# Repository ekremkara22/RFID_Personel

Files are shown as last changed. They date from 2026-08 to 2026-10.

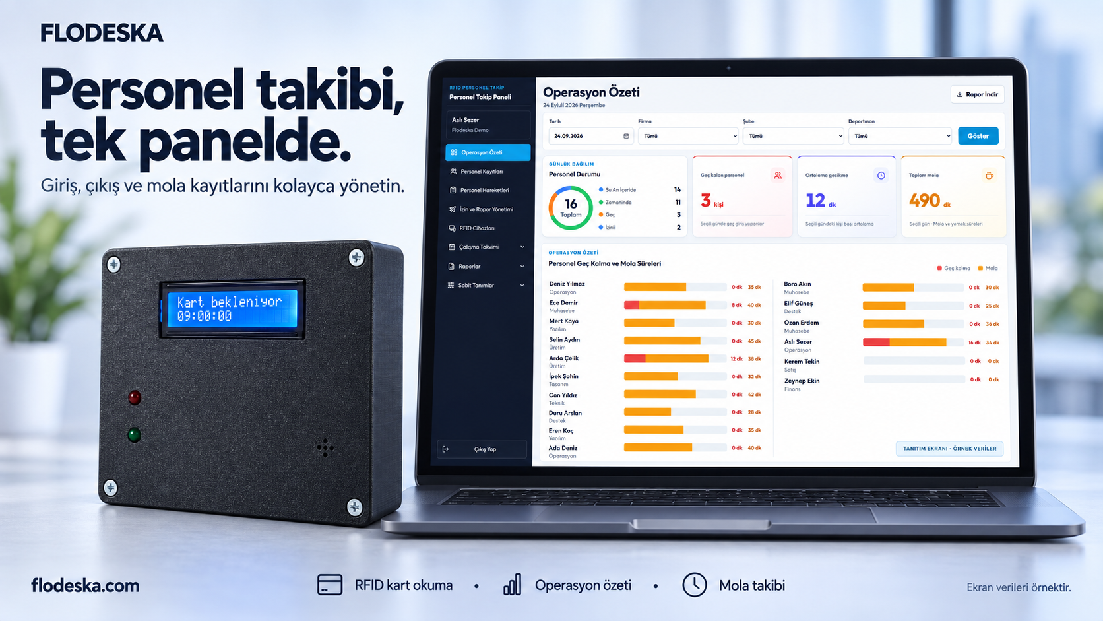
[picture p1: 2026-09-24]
public/images/marketing/flodeska-tanitim-yatay-v1.png

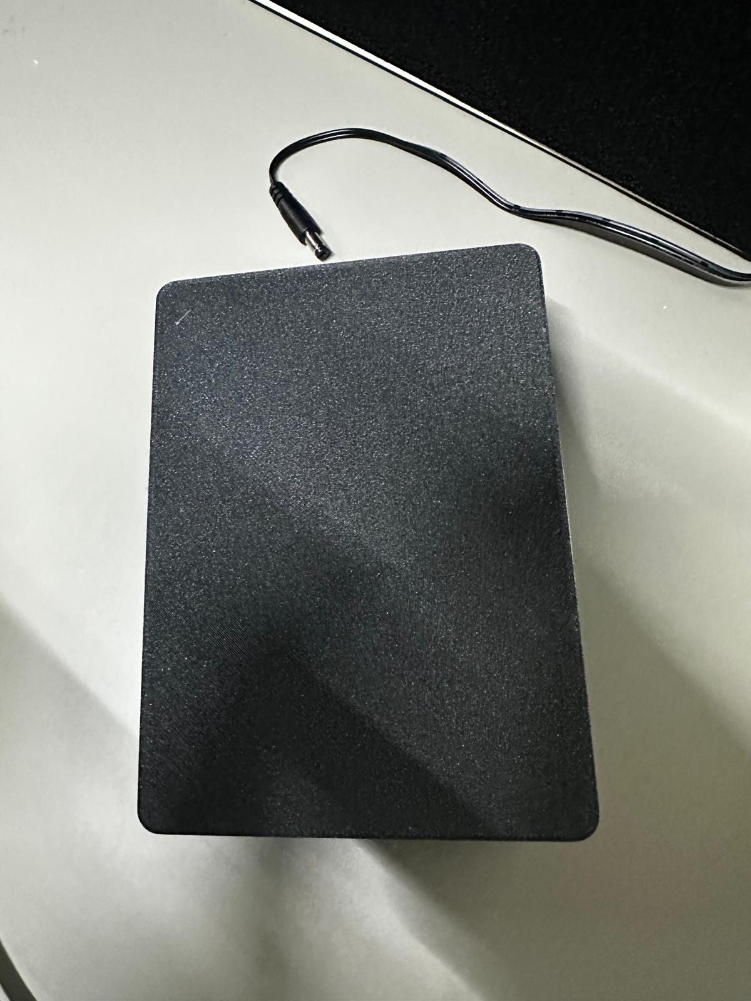
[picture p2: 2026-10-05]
UrunGorsel/Gorseller/WhatsApp Image 2026-09-24 at 16.05.19 (3).jpeg

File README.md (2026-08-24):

# RFID Personel Takip

RFID kart tabanli personel takip paneli. Bu repo web paneli, veritabani modeli ve ESP32/RFID cihaz entegrasyonu icin kullanilir; eski mobil uygulama kodlari devre disi birakilmistir.

## Getting Started

First, run the development server:

```bash
npm run dev
# or
yarn dev
# or
pnpm dev
# or
bun dev
```

Open [http://localhost:3000](http://localhost:3000) with your browser to see the result locally.

You can start editing the page by modifying `app/page.tsx`. The page auto-updates as you edit the file.

This project uses [`next/font`](https://nextjs.org/docs/app/building-your-application/optimizing/fonts) to automatically optimize and load [Geist](https://vercel.com/font), a new font family for Vercel.

## Learn More

To learn more about Next.js, take a look at the following resources:

- [Next.js Documentation](https://nextjs.org/docs) - learn about Next.js features and API.
- [Learn Next.js](https://nextjs.org/learn) - an interactive Next.js tutorial.

You can check out [the Next.js GitHub repository](https://github.com/vercel/next.js) - your feedback and contributions are welcome!

## Deploy on Vercel

The easiest way to deploy your Next.js app is to use the [Vercel Platform](https://vercel.com/new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) from the creators of Next.js.

Check out our [Next.js deployment documentation](https://nextjs.org/docs/app/building-your-application/deploying) for more details.

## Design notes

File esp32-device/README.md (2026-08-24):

# RFID Personel ESP32 Device

Bu klasor, firma girisine koyulacak ESP32 + OLED cihazinin firmware taslagini icerir.

## Yeni Wi-Fi kurulum akisi

Cihaz artik Wi-Fi adini ve sifresini koda sabitlemek zorunda degil.

1. ESP32 acildiginda kalici bellekte kayitli Wi-Fi bilgisi arar.
2. Kayitli bilgi varsa bu aga baglanmayi dener.
3. Baglanabilirse `https://flodeka.com/api/device/qr/sync` endpoint'inden QR token almaya devam eder.
4. Kayitli bilgi yoksa veya aga baglanamazsa kendi kurulum agini acar.
5. OLED ekranda kurulum agi gorunur: `RFIDPersonel-XXXXXX`.
6. Telefon ile bu Wi-Fi agina baglan.
7. Tarayici otomatik acilmazsa `http://192.168.4.1` adresine git.
8. ESP32'nin gordugu Wi-Fi aglarindan kendi agini sec, sifreyi gir ve kaydet.
9. OLED'de kaydedildi mesaji gorundukten sonra ESP32 uzerindeki reset tusuna bas.
10. Cihaz yeniden acilinca kaydedilen Wi-Fi bilgisi ile internete baglanir ve QR uretmeye devam eder.

## Mimari

ESP32 dogrudan MySQL veritabanina baglanmaz.

Daha dogru akis:

1. ESP32 Wi-Fi'ye baglanir.
2. Sunucudaki `/api/device/qr/sync` endpoint'ine `secretKey` ile POST atar.
3. Sunucu cihaz icin aktif `qrToken` degerini dondurur.
4. ESP32 bu token'i OLED uzerinde QR olarak gosterir.
5. ESP32 duzenli araliklarla endpoint'i tekrar cagirir.
6. Eger sunucudaki token degismisse OLED'deki QR da hemen degisir.

Bu sayede:

- 5 saniyelik token yenileme veritabaninda merkezi olarak yonetilir
- Personel basarili `Giris` veya `Cikis` yaptiginda backend token'i aninda yeniler
- ESP32 bir sonraki poll'da bunu gorup QR'i hemen yeniler

## Dosyalar

- `checkinqr_device/checkinqr_device.ino`: Arduino IDE / ESP32 icin ana firmware
- `qrcode.c`, `qrcode.h`: QR olusturma kutuphanesi

## Gerekli kutuphaneler

Arduino IDE Library Manager ile su kutuphaneleri kur:

- `Adafruit GFX Library`
- `Adafruit SSD1306`
- `ArduinoJson`
- `QRCode`

ESP32 core ile gelen su kutuphaneler de kullanilir:

- `WiFi`
- `WebServer`
- `DNSServer`
- `Preferences`
- `HTTPClient`
- `WiFiClientSecure`

## Donanim varsayimi

- Kart: ESP32 Dev Module
- Ekran: SSD1306 128x64 I2C OLED
- I2C adresi: `0x3C`
- Reset: ESP32 kart uzerindeki `EN/RST` tusu
- Wi-Fi durum LED'i: `GPIO 5` / kart uzerinde `D5`

## LED ve reset butonu baglantisi

Wi-Fi baglaninca yanacak yesil LED:

```text
ESP32 D5 / GPIO 5 -> LED uzun bacak (+)
LED kisa bacak (-) -> 220R veya 330R direnc -> GND
```

Harici reset butonu kullanmak istersen:

```text
Buton ucu 1 -> EN
Buton ucu 2 -> GND
```

Not: Harici reset butonu koda bagli degildir; ESP32'yi donanimsal olarak yeniden baslatir.

## Ayarlanacak alanlar

`checkinqr_device.ino` icindeki su degerleri kontrol et:

- `API_BASE_URL`: varsayilan `https://flodeka.com`
- `DEVICE_SECRET_KEY`: panelde tanimli cihaz secret key degeri

Wi-Fi bilgisi artik web kurulum ekranindan kaydedilir.

Istersen firmware icine ilk kurulum icin varsayilan Wi-Fi bilgisi gomulebilir:

```cpp
const char* DEFAULT_WIFI_SSID = "WiFi_Adi";
const char* DEFAULT_WIFI_PASSWORD = "WiFi_Sifresi";
```

Bu degerler bos birakilirsa cihaz ilk acilista kurulum agi acar.

## Sunucu endpoint'i

POST `https://flodeka.com/api/device/qr/sync`

Ornek body:

```json
{
  "secretKey": "cihaz-secret-key"
}
```

Ornek cevap:

```json
{
  "deviceId": "uuid",
  "deviceName": "On Kapi ESP32",
  "companyId": "uuid",
  "qrToken": "aktif-uuid-token",
  "qrUpdatedAt": "2026-04-11T12:00:00.000Z",
  "qrExpiresAt": "2026-04-11T12:00:05.000Z",
  "refreshIntervalSeconds": 5
}
```

## Onemli not

Backend tarafinda token 5 saniyede bir degisecek sekilde ayarli.
Ancak personel basarili `Giris` veya `Cikis` yaptiginda token hemen yenileniyor.

Bu nedenle ESP32 kodunda poll araligini 1 saniye tuttuk.
Boylece cihaz, 5 saniyeyi beklemeden yeni token'i hizlica alir.

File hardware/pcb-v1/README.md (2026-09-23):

# RFID taşıyıcı PCB V0.1 - V4 kutu

**Durum: elektrik bağlantıları tanımlanmış, parçaları yerleştirilmiş, bakır yolları henüz çizilmemiş ilk taslak. Üretime hazır değildir.**

Bu paket 30 pinli ESP32 DevKit V1'i sökülebilir iki soket üzerinde kullanır. Mevcut çalışan firmware'in GPIO bağlantıları korunur. ESP32, LCD veya RC522'nin fiziksel örnekleri bu çalışma sırasında ölçülmedi; kart çalıştırılmadı. Gerber üretilmedi.

## Dosyalar

- `rfid_carrier_v01.kicad_pro`: KiCad proje dosyası.
- `rfid_carrier_v01.kicad_sch`: gömülü sembolleri olan elektrik şeması; aynı isimli net etiketleri birbirine bağlıdır.
- `rfid_carrier_v01.kicad_pcb`: 128 × 58 mm, 1,6 mm, iki katmanlı taslak; net atamaları ve anten/vida bölgeleri var, yollar yok.
- `RFID_Carrier.pretty/`, `RFID_Carrier.kicad_sym`, kütüphane tabloları: taşınabilir yerel parçalar. Footprint'ler fiziksel doğrulama bekliyor.
- `connections.csv`: her bileşenin her bacağı ve bağlandığı hat.
- `bom.csv`: parça listesi; ESP32 modülü, LCD, RC522, iki LED, buzzer, kutu, kablo, eş soketler ve bağlantı elemanları ayrıca gerekir.
- `design.json`: parametrik elektrik ve yerleşim kaynağı.
- `pcb_yerlesim.png`: yerleşim görünümü; üretim çizimi değildir.
- `v4_geometry.json`: kaynak STL özetleri, dosya hash'leri ve kesitlerden bulunan geometriler.
- `validation.json`, `file_validation.json`: yapılan sınırlı kontroller ve yapılmayanlar.
- `../../output/pdf/rfid_pcb_v01_inceleme.pdf`: 1:1 mekanik kontrol sayfası ve devre özeti.

KiCad 8+ dosya sözdizimi hedeflendi. Bu makinede KiCad bulunmadığından uygulamada açılış, ERC ve DRC henüz doğrulanmadı. `.kicad_pro` dosyasını açın; şema ve kartta karşılıklı referans UUID'leri bulunur. Şemadan PCB güncellemesi yapmadan önce yedek alın.

## V4'ten ölçülen mekanik düzen

Kaynaklar `output/enclosure_v4/gövde.stl` ve `kapak.stl` dosyalarıdır. STL birimi proje bağlamına göre mm kabul edilir. Dosyalardaki negatif yerleşim koordinatları normalize edildi; **gövdenin minimum X/Y köşesi (0,0)** kabul edilir. Çizimler bu XY koordinatlarını gösterir, kullanıcı bakış açısına göre ön/arka isimlendirme yapılmaz.

| Özellik | Değer |
|---|---|
| Gövde dışı | 150 × 110 × 52 mm |
| Kapak STL sınırları | 150 × 110 × 8,498 mm; bu üçüncü ölçü ayaklarla toplam zarf, kapak et kalınlığı değildir |
| PCB sınırı | X=4…132; Y=39…97 mm |
| PCB boyutu | 128 × 58 × 1,6 mm |
| PCB alt yüzeyinin hedef yüksekliği | Gövde STL tabanından Z=10 mm |
| ESP32 bölgesi delikleri | X=8,05 / 51,95; Y=43,10 / 66,90; geçiş çapı 2,8 mm |
| Eski plaket bölgesi delikleri | X=83,41 / 126,59; Y=48,41 / 91,59; geçiş çapı 3,2 mm |
| Delik merkezlerinin STL kesitleriyle farkı | Taslak kontrolünde 0,06 mm'den az; baskı toleransı değildir |

Sekiz ayağın tepe düzlemi Z=10 mm. Kart bu ayakların üzerine oturur; eski ayrı delikli plaket çıkarılır. ESP32 PCB'ye takılır. Sol bölgedeki vidaların başları ESP32 altında kalabilir: önce taşıyıcı kart vidalanır, sonra ESP32 takılır. Uygun küçük başlı vidalar/yalıtkan pullar seçilir. Mevcut V4 STL dosyaları değiştirilmedi.

**USB yüksekliği kesinleşmedi:** mevcut gövde USB açıklığı yaklaşık Z=9…21 mm. Taşıyıcı PCB ve soket ESP32'yi yükseltir. DevKit'in alt yüzeyi yaklaşık `10 + 1,6 + soketin etkin yüksekliği` mm olur. Soket yüksekliği, USB metal gövdesi ve takılı kablo fişi birlikte denenmelidir. Gerekirse düşük profilli soket veya V4 yan pencere revizyonu gerekir. Kutuya kusursuz oturduğu iddia edilmez.

Kapak, gövdeyle montaj konumuna çevrilmeden LCD/RC522 koordinatları doğrudan üst üste konulamaz. Bu nedenle taslak kapak modüllerine doğrudan geçmeli soket kullanmaz; esnek kablo bağlantısı bırakır. DevKit dış zarfı ve soket yeri önceki proje ölçülerinden varsayımdır, V4 STL ESP32 pinlerini içermez.

## Elektrik düzeni

`J1 → F1 → +5V` hattı LCD, buzzer ve U1'i besler. `JP1` takılıyken ESP32 VIN'e gider. ESP32'nin mevcut regülatöründen alınan 3V3 RC522'yi besler. Bütün GND'ler ortaktır.

- **J6/J7:** iki 1×15 dişi soket. 2,54 mm pin adımı, **25,40 mm sıra arası varsayım**. Üstten PCB görünümünde USB solda, anten sağda. J6 soldan VIN ile; J7 soldan 3V3 ile başlar. `connections.csv` bütün sırayı verir. Kart üzerindeki gerçek etiketlerle tek tek karşılaştırılmalı.
- **J2:** RC522, pinler soldan `SS, SCK, MOSI, MISO, IRQ(NC), GND, RST, 3V3`. Reader soketinin sırası farklıysa kablo çaprazlanır; isimler esas alınır. R7/R8 SCK ve MOSI üzerinde 33 Ω seri dirençtir. SS, R6 ile 3V3'e çekilir.
- **J3:** LCD'nin 1…16 pinleriyle aynı numaralar; RW GND, D0…D3 boş. Altı sinyal U1 üzerinden gider. Bu tasarım I2C değildir.
- **U1:** SN74AHCT244N, DIP-20. 5V beslemede 3,3V girişleri kabul ederek LCD'ye 5V sinyal verir. Her iki OE GND; kullanılmayan girişler GND, çıkışlar NC. RN1 LCD kontrol girişlerini açılışta düşük tutar. RN1, ortak ucu pin 1 olan **bussed** 8×10 kΩ SIP-9 olmalıdır.
- **RV1:** 10 kΩ kontrast trimeri. Pin 1 GND, 2 sürgü/VO, 3 +5V; gerçek modelin pin sırası doğrulanmalı.
- **R5:** LCD arka aydınlatması için başlangıç 330 Ω. Loş olabilir; LCD veri sayfası ve ölçülen akıma göre seçilir. Mevcut LCD'de dahili direnç bulunması doğrulanmadan kısa devre edilmez.
- **J4:** yeşil anot, GND, kırmızı anot, GND. R1/R2 220 Ω seri dirençler kart üzerindedir.
- **J5:** pin 1 +5V, pin 2 Q1 kolektörü. GPIO14 → R3 1 kΩ → BC337 base; emitter GND. R4 100 kΩ base-emitter direnci açılışta kapalı tutar. D1 katot/çizgi +5V, anot kolektör. D1'in ve base sürüşünün uygunluğu gerçek buzzer akımına göre doğrulanmalı; BC337'nin katalog maksimum akımı bu devrenin izin verilen buzzer akımı değildir.
- **C1:** 470 µF/16V; mevcut parçanın çapı/pin aralığı 8/3,5 mm varsayımıyla uyuşmuyorsa footprint değiştirilir. Yerel 100 nF ve 10 µF kondansatörler eklendi.
- **TP1/TP2/TP3:** +5V, +3V3 ve GND ölçüm noktaları.

F1, MF-R075 0,75 A PTC ön seçimidir. Kutudaki sıcaklık, başlangıç akımı ve üzerindeki gerilim düşümü ölçülmeden sonlandırılmaz. 5V hattı U1 için en az 4,5V olmalı. Burada 9/12V düşürücü, ters kutup koruması veya USB/harici güç OR-ing devresi yoktur. Regüle 5V ve doğru polarite gerekir.

**USB ile harici besleme aynı anda bağlanmaz.** JP1 çift güç kaynağı güvenliği sağlamaz. İlk prototipte programlamayı ESP32'yi soketten çıkarıp USB'ye bağlayarak yapın; güç kesikken yeniden takın. Sonraki revizyonda servis sırasında eşzamanlı güç istenirse uygun güç seçimi eklenir.

## Kablo kalabalığı nasıl azalıyor?

ESP32 ile dirençler, transistör, besleme dağıtımı ve kondansatörler arasında kablo olmayacak; bunlar PCB yollarına dönüşecek. Kapaktaki modüller için dört demet kalacak: LCD (16'lı şerit, 12 aktif hat), RC522 (8'li, 7 aktif), LED'ler (4'lü), buzzer (2'li). Jak için ayrıca iki güç teli var. Henüz yollar çizilmediği için mevcut dosya bu işlevi fiziksel olarak gerçekleştiren bitmiş kart değildir.

J2…J5 için çizilen footprint'ler genel 2,54 mm pin sıralarıdır; belirli bir kilitli konektörün mekanik zarfı doğrulanmış değildir. Sipariş öncesi tek seri kutuplu/kilitli soket seçilip gerçek footprint'e geçilir. Kablo pin 1 yönleri iki uçtan multimetreyle kontrol edilir.

## Üretimden önce kapanması gerekenler

1. PDF'yi **gerçek boyut/%100**, sayfaya sığdırma kapalı basın; 50 mm ölçek çizgisini cetvelle ölçün. DevKit soketleri, sekiz vida ve kart sınırını gerçek parçalarla kontrol edin.
2. DevKit iki sıra merkezini, USB yönünü, J6/J7 pin sırasını, soket yüksekliğini ve kablo fişi açıklığını doğrulayın. 30 pinli DevKit V1 adı tek başına bütün klonların aynı ölçüde olduğunu garanti etmez.
3. Trimer, terminal, kondansatör, transistör ve soket modellerini kesinleştirin; footprint'leri düzeltin. Boşluk kontrolleri yalnızca taslaktaki zarflara dayanır.
4. KiCad'de açın. Şema ERC uyarılarını gerçek güç kaynaklarını ve bağlantıları göz önünde bulundurarak çözün. Bağlantı etiketlerinin şemadan çıkan netlist ile eşleştiğini doğrulayın; sadece bütün uyarıları susturmayın.
5. İki katmanlı bakır yolları çizin. Başlangıç kuralları: sinyal 0,30 mm; güç 0,80 mm; minimum açıklık 0,25 mm; bunlar üretici kuralları ve akım/ısı hesabıyla sonlandırılır. Wi-Fi anten bölgesinde iki katmanda da bakır, via ve hat bırakmayın. Şu anki anten boşluğu muhafazakâr bir taslak; gerçek anten sınırı ve üretici önerileriyle doğrulanmalı. Vida bölgelerinden bakır geçirmeyin. Uygun bölgelerde GND dolgusu ve kısa dönüş yolları oluşturun.
6. DRC, açık bağlantı kontrolü, gerçek bileşenlerle 3B çakışma ve kapak kapalı halde kablo boşluklarını kontrol edin. Eksiksiz 3B doğrulama yapılmadan "V4'e kesin uyumlu" kabul etmeyin.
7. Gerber ve delik dosyalarını **bu adımlardan sonra** üretin. Küçük deneme adedi yaptırın; nihai BOM'a göre elle monte edin.
8. Akım sınırlı regüle 5V ile modüller çıkarılmış halde kısa devre/besleme kontrolü yapın. Gücü kesip ESP32'yi ekleyin, 3V3 ölçün; sonra ekran, RFID ve buzzerı sırayla deneyin. Wi-Fi gönderimi + arka ışık + buzzer birlikteyken reset/gerilim düşümü olmamalı. Kapak açık/kapalı RFID okuma mesafesini ve Wi-Fi kararlılığını karşılaştırın.

## İkinci sürüm: geliştirme kartını kaldırmak

İlk PCB donanım arayüzünü sabitler: LCD paralel, RC522 SPI, iki LED, buzzer. İkinci revizyonda DevKit yerine uygun bir **ESP32 modülü** doğrudan lehimlenebilir. ESP32 çipini ve RF devresini sıfırdan tasarlamak zorunlu değildir.

Bu değişimde DevKit'in sağladığı 3,3V regülatör, EN/BOOT devresi, programlama arayüzü, besleme ayırma ve test noktaları ana karta taşınır. Aynı ESP32 ailesi/modülü ve GPIO'lar korunursa uygulama mantığı büyük ölçüde yeniden kullanılabilir; farklı aileye geçiş yeniden pin/çevrebirim doğrulaması gerektirir.

"Standart gömülü yazılım" için sonraki iş: pinleri kart profiline ayırmak, sürüm numaralı derleme ve bağımlılıklar, cihaz kimliği/provizyonlama, güvenli güncelleme ve test prosedürü oluşturmak. Geliştirme kartını kaldırmak tek başına yazılımı standartlaştırmaz. Bu çalışmada çalışan `.ino` değiştirilmedi.

## Kaynaklar

- Yerel bağlantılar: `esp32-device/rfid_personel_device/BAGLANTI_DOKUMANI.md` ve aynı dizindeki firmware.
- [TI SN74AHCT244 veri sayfası](https://www.ti.com/lit/ds/symlink/sn74ahct244.pdf): pin düzeni, TTL giriş eşiği, besleme aralığı.
- [onsemi BC337 veri sayfası](https://www.onsemi.com/pdf/datasheet/bc337-fsc-d.pdf): C-B-E bacak sırası ve elektriksel sınırlar.
- [Bourns MF-R veri sayfası](https://bourns.com/docs/product-datasheets/mf-r.pdf): PTC ölçüleri, akım ve sıcaklık karakteristikleri.
- [Espressif ESP32 yerleşim kılavuzu](https://docs.espressif.com/projects/esp-hardware-design-guidelines/en/latest/esp32/pcb-layout-design.html): modül anten bölgesi ve yerleşim.
- [KiCad PCB dosya biçimi](https://dev-docs.kicad.org/en/file-formats/sexpr-pcb/) ve [şema biçimi](https://dev-docs.kicad.org/en/file-formats/sexpr-schematic/).

## Yeniden üretme

Python 3, numpy, Pillow; PDF için reportlab. Çalışma dizini projenin kökü:

```text
python hardware/pcb-v1/inspect_stl.py
python hardware/pcb-v1/build_design.py
python hardware/pcb-v1/validate_files.py
python hardware/pcb-v1/build_pdf.py
```

Üreteç aynı adlı çıktıları yeniden yazar. KiCad'de el ile yapılan değişikliklerin üzerine çalıştırmayın; üreteci veya dosyaları tek kaynak olarak seçin. Hiçbir komut kaynak STL'leri veya firmware'i değiştirmez.

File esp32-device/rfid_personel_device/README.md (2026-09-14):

# RFID Personel ESP32 Cihaz Kodu

Bu klasor tek RFID okuyucu ile personel giris-cikis, mola giris-cikis ve mesai cikis hareketlerini web API'ye gondermek icin hazirlandi.

## Gerekli Arduino kutuphaneleri

- MFRC522
- LiquidCrystal
- ArduinoJson

## Varsayilan pinler

| Parca | ESP32 pini |
| --- | --- |
| RC522 SDA/SS | GPIO 5 |
| RC522 RST | GPIO 27 |
| RC522 SCK | GPIO 18 |
| RC522 MISO | GPIO 19 |
| RC522 MOSI | GPIO 23 |
| 2x16 paralel LCD RS | GPIO 32 |
| 2x16 paralel LCD E | GPIO 25 |
| 2x16 paralel LCD D4 | GPIO 22 |
| 2x16 paralel LCD D5 | GPIO 21 |
| 2x16 paralel LCD D6 | GPIO 16 / RX2 |
| 2x16 paralel LCD D7 | GPIO 17 / TX2 |
| Yesil LED | GPIO 26 |
| Kirmizi LED | GPIO 33 |
| Aktif buzzer sinyali | GPIO 14 / D14 |

LCD, I2C donusturucu olmadan 4-bit paralel modda kullanilir. Ayrintili guc,
kontrast ve buzzer baglantisi icin `BAGLANTI_DOKUMANI.md` dosyasina bak.

## Ilk kurulum

1. Arduino IDE icinde `rfid_personel_device.ino` dosyasini ac.
2. Kart olarak ESP32 sec.
3. Kodu ESP32'ye yukle.
4. Cihazda kayitli Wi-Fi/secret yoksa `RFIDPersonel-XXXXXX` adinda ag acar.
5. Telefonda bu aga baglan ve tarayicida `192.168.4.1` adresini ac.
6. Wi-Fi, API adresi ve cihaz secret key bilgisini kaydet.

Varsayilan API adresi:

```text
http://13.143.223.183:3002
```

Secret key bilgisini firma admin panelindeki RFID cihaz detayindan alabilirsin.

## Calisma mantigi

- Cihaz baglandiginda `/api/device/heartbeat` endpoint'ine bilgi yollar, panelde aktif gorunur.
- RFID kart okutulunca `/api/device/rfid/scan` endpoint'ine kart UID bilgisini gonderir.
- Web tarafinda hareket turu calisma takvimine gore tahmin edilir:
  - Gunun ilk hareketi: giris
  - Mola baslangic/bitiş saatlerine +-30 dakika yakin hareket: mola giris/cikis
  - Mesai bitisine +-30 dakika yakin hareket: cikis
  - Yanlis tahmin olursa firma admini Personel Hareketleri sayfasindan kaydi duzeltebilir.

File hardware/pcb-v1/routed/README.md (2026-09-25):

# RFID taşıyıcı PCB V0.2 — V4 kutu

Bu klasör V0.1 yerleşim taslağının bakır yolları çizilmiş prototip revizyonudur.
30 pin ESP32 DevKit V1 sökülebilir iki 1×15 dişi sokete takılır. Firmware GPIO
bağlantıları, V4 kart sınırı ve sekiz vida deliği korunur.

**Fiziksel prototip henüz üretilmedi veya çalıştırılmadı.** Dijital kontrollerin
sonuçları `validation.json`, `drc.json` ve `erc.json` içindedir. Siparişten önce
aşağıdaki üç fiziksel kontrol yapılmalıdır; bu dosyalar ölçülmemiş parçaların
mekanik uyumunu garanti etmez.

## Açılacak dosyalar

- `rfid_carrier_v01.kicad_pro`: proje; dosya adı şema/PCB referanslarını korumak için sabit kaldı, revizyon V0.2'dir.
- `rfid_carrier_v01.kicad_pcb`: iki katmanlı bakır yolları ve GND dolguları.
- `rfid_carrier_v01.kicad_sch`: elektrik şeması; global hat adları PCB ile aynıdır.
- `pcb_routed.png`: gerçek PCB geometrisinden üretilen üst/alt bakır görünümü.
- `mechanical_1to1.svg`: fiziksel parçalarla kontrol için %100 boyutta baskı şablonu.
- `gerber/`: iki bakır, iki maske, iki baskı katmanı, kart sınırı ve ayrı PTH/NPTH delik dosyaları.
- `connections.csv`, `bom.csv`: bağlantılar ve taşıyıcı kartın parça listesi.
- `native.net`: KiCad'in gerçek şemadan dışa aktardığı netlist.
- `validation.json`: şema–PCB–kaynak bağlantı karşılaştırması, hat uzunlukları ve PCB SHA-256 özeti.
- `RFID_Carrier.pretty/`, `RFID_Carrier.kicad_sym`, `*-lib-table`: proje ile taşınan yerel kütüphaneler.

Bir üst klasördeki V0.1 dosyaları ve eski inceleme PDF'si arşiv taslağıdır;
üretim için bu revizyonun dosyaları esas alınır.

## Tasarım kuralları ve değişiklikler

| Özellik | V0.2 |
|---|---|
| Kart | 128 × 58 mm, 1,6 mm, 2 katman; başlangıç 35 µm / 1 oz bakır |
| Kart koordinatları | V4 gövdesi normalize XY; X=4…132, Y=39…97 mm |
| Sinyal yolları | 0,30 mm |
| Güç yolları | 0,50 mm; GND ayrıca iki yüzeyde dolgu |
| Minimum elektriksel açıklık | 0,20 mm |
| Via | 1,00 mm bakır / 0,50 mm delik |
| ESP32 soket pedleri | 1,60 mm bakır / 1,00 mm delik; 2,54 mm adım |
| Soket sıra merkezleri | **25,40 mm varsayım — gerçek kartta ölçülecek** |
| Anten boşluğu | X=49…76, Y=39…85 mm; iki katmanda yol/via/dolgu yok |
| Vida boşlukları | 2,8 mm delikte 3,0 mm; 3,2 mm delikte 3,5 mm yarıçaplı bakırsız bölge |

V0.1'deki 0,80 mm güç yolu ve 0,25 mm açıklık önerisi bu yerleşimde soket
sıralarından geçişi engellediği için revize edildi. R7/R8 seri dirençleri ESP32
tarafına alındı; F1, C3, C5, Q1 ve RV1 montaj boşlukları düzeltildi. Güç
kaynakları şemada PWR_FLAG ile belirtildi. Kontroller için ihlal istisnası
eklenmedi. NPTH deliklerin koruma bölgesinde bulunabilmesi için bu bölgelerde
pad yasağı kullanılmaz; gerçek bileşen bakır pedleri ayrıca denetlenir.

## Siparişten önce üç kontrol

1. **ESP32:** iki pin sırası merkezini ölçün; 25,40 mm olmalı. Üstten bakışta
   USB solda, anten sağda; J6 soldan VIN, J7 soldan 3V3 ile başlar. Kart
   etiketlerini `connections.csv` ile tek tek eşleştirin.
2. **Kutu:** `mechanical_1to1.svg` dosyasını gerçek boyut / %100 basın; 50 mm
   çizgiyi cetvelle doğrulayın. Sekiz vida, kart sınırı, soket yüksekliği ve USB
   fişini V4 baskıda deneyin. PCB altı hedef Z=10 mm; mevcut USB penceresi
   yaklaşık Z=9…21 mm. Soket ESP32'yi yükselttiği için pencere değişikliği gerekebilir.
3. **BOM:** RV1 sürgü bacağı, J1 5,08 mm terminal, BC337 C-B-E, elektrolitik
   çap/adım, RN1 ortak bacak ve seçilen dişi soketlerin gövdelerini kontrol edin.
   J2…J5 genel 2,54 mm pin sıralarıdır; kilitli konnektör gövdeleri doğrulanmadı.

## Montaj ve ilk çalıştırma

- J1 yalnız **regüle 5 V DC** içindir. 12 V girişi, ters kutup koruması ve USB
  ile harici güç arasında otomatik seçim devresi yoktur. İlk programlamada
  ESP32'yi taşıyıcıdan çıkarıp USB ile programlayın. Harici beslemeyle kullanımda JP1 takılır.
- U1 **SN74AHCT244N DIP-20** olmalıdır. RN1 ortak ucu pin 1 olan 8×10 kΩ
  bussed SIP-9 ağıdır. LCD paralel 4-bit arayüz kullanır; I2C adaptör gerekmez.
- J2 RC522 sadece 3,3 V'tur. Soket sırası isimle eşleştirilir; kablo renkleri
  esas alınmaz. RFID kablosunu kısa tutun. Uzun bakır hatların/kablonun gerçek
  SPI okuma kararlılığı donanım üzerinde denenmelidir.
- R5=330 Ω LCD arka ışığı için başlangıç değeridir; ekranın gerçek akımı ve
  dahili direnci ölçülmeden köprülemeyin. Buzzer, Q1 ve D1 uygunluğu gerçek
  buzzer akımına bağlıdır. F1'in 0,75 A değeri kart için doğrulanmış akım kapasitesi değildir.
- Önce modüller çıkarılmışken kısa devre ve kutup kontrolü yapın. Akım sınırlı
  5 V ile besleyin; sonra gücü kesip ESP32, ekran, RC522 ve buzzerı sırayla ekleyin.
  Wi-Fi + arka ışık + buzzer eşzamanlı çalışırken 5 V / 3V3 düşümünü, resetleri,
  sıcaklığı ve kapak kapalı RFID menzilini kontrol edin.

## Doğrulama ve yeniden üretme

Doğrulama için resmi imzalı KiCad **10.99.0-4384-g95775e4647** CLI kullanıldı.
PCB/şema kaynakları KiCad 8 dosya sözdizimini korur; KiCad 8 uygulamasıyla
ayrıca denenmedi. Freerouting yerel çalıştırıldı; tasarım harici yönlendirme
servisine yüklenmedi. Donanım güç/ısı, sinyal bütünlüğü veya RF laboratuvar testi yapılmadı.

`prepare.py` yerleşim ve şema kaynağını üretir ve **mevcut bakır yollarını siler**.
`export_dsn.py` yönlendirme girdisini, `import_ses.py` SES'ten bakır yollarını
oluşturur. `finish_board.py` GND bölgelerini ekler; dolgu KiCad tarafından
yapılır. `review.py` gerçek PCB dosyasından kontrol raporu ve görsel üretir.
El ile düzenlenmiş PCB üzerine `prepare.py` çalıştırmayın.

Şema değişikliğinde ERC, şema–PCB netlist karşılaştırması ve DRC; her PCB
değişikliğinde dolgu yenileme, tüm DRC kontrolleri ve Gerber/delik dışa aktarımı
tekrarlanmalıdır. `validation.json` içindeki SHA-256, raporun hangi PCB'ye ait
olduğunu gösterir.

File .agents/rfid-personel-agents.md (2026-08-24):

# RFID Personel Takip Agent Yapisi

Bu dosya projede calisirken sorumluluk alanlarini ayirmak icin kullanilir.

## Ana Orchestrator

- Is akisini parcalara ayirir ve degisiklikleri tek hedefe baglar.
- Next.js dokumanlari yerelde varsa once `node_modules/next/dist/docs/` altindaki ilgili rehberi kontrol eder.
- Deploy, test ve geri bildirim akisini kapatir.
- Tum agent'lar web ekranlarini mobil ve tablet kullanimina uygun dusunur; ozellikle Firma Admin panelinde tablo, form ve dashboardlar dar ekranda okunabilir ve kullanilabilir kalmalidir.

## Personel Agent

- `src/app/dashboard/employees` ekranlari ve personel server action'larindan sorumludur.
- RFID kart alanlari, personel arama, duzenleme, silme ve aktivasyon akisini korur.
- Personel kayit, rapor ve hareket ekranlarini masaustu kadar tablet ve mobil kullanimda da islenebilir tutar.
- Koordinat, GPS veya mobil uygulama bagimliligi eklemez.

## Firma Agent

- Super admin firma listeleme, firma detay, firma admin bilgileri ve firma silme akisini yonetir.
- Firma Admin deneyiminde dashboard, rapor, izin ve sabit tanim ekranlarinin responsive davranisini korur.
- Firma detayinda cihaz atama islemlerinin sadece super admin yetkisinde kalmasini saglar.

## SQL Agent

- `prisma/schema.prisma`, seed verileri ve veritabani gecislerinden sorumludur.
- RFID kart ID alanini benzersiz tutar.
- Dinamik QR token, enlem, boylam ve konum dogrulama kolonlarini geri getirmez.

## Cihaz Agent

- `src/app/dashboard/devices` ve `src/app/api/device/rfid/scan` alanlarini yonetir.
- Firma adminin sadece kendisine atanmis cihazlari gormesini ve cihaz adini duzenlemesini saglar.
- ESP32 firmware fazina gecilene kadar web/API sozlesmesini sade ve kararlı tutar.

## ESP32 Agent

- Web tabani tamamlandiktan sonra `esp32-device` altindaki firmware'i RFID okuyucu akisana cevirir.
- Hedef API: `POST /api/device/rfid/scan`
- Cihazdan beklenen minimum veri: `secretKey`, `rfidCardId`.

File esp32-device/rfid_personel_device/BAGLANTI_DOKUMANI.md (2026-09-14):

# ESP32 RFID Personel Cihazı — Montaj ve Bağlantı Belgesi

Bu belge çalışan `rfid_personel_device.ino` firmware'indeki pinlere göre, kalıcı
lehimli montaj sırasında çıktı alınıp kullanılmak üzere hazırlanmıştır.

## 1. Önemli güvenlik kuralları

- Bütün bağlantıları adaptör prizden çekiliyken yap.
- Adaptör çıkışı regüle `5V DC / 1A` olmalıdır. 9V veya 12V bağlama.
- Adaptör `+5V` hattını yalnızca ESP32 `VIN`, LCD ve buzzer beslemesinde kullan.
- ESP32 `3V3` pinine kesinlikle 5V bağlama.
- RC522'ye kesinlikle 5V verme; yalnızca ESP32 `3V3` pininden besle.
- Elektrolitik kondansatörü ters bağlama.
- Adaptör VIN'e bağlıyken ESP32'ye bilgisayar USB'sinden ayrıca güç verme.
- İlk enerjiyi vermeden önce multimetreyle kısa devre ve gerilim kontrolü yap.

## 2. Kullanılacak parçalar

- ESP32 geliştirme kartı (`VIN`, `3V3` ve `GND` pinli)
- RC522 RFID okuyucu
- 2x16 paralel LCD (I2C dönüştürücüsüz)
- Yeşil LED
- Kırmızı LED
- 2 adet `220 ohm` LED direnci
- 5V aktif buzzer
- 1 adet `BC337` NPN transistör
- 1 adet `1K ohm` buzzer base direnci
- 1 adet `470 uF / 16V` elektrolitik kondansatör
- 1 adet `100 nF` seramik kondansatör
- Regüle `5V DC / 1A` adaptör
- Jak soketi, klemens, kablo ve pertinaks

`2N2222` bu montajda kullanılmayacak; BC337 için yedek olarak saklanacaktır.
Transistörlerin bacak sıraları aynı olmayabileceği için birbirlerinin yerine
kontrol etmeden takılmamalıdır.

Manyetik/bobinli buzzer kullanılıyorsa ayrıca `1N4148` veya `1N4007` koruma
diyodu gerekir. Bu belge iki bacaklı 5V aktif buzzerı esas alır.

## 3. ESP32 pin özeti

| Görev | ESP32 kart etiketi | GPIO |
| --- | --- | --- |
| RC522 SDA/SS | D5 | GPIO 5 |
| RC522 SCK | D18 | GPIO 18 |
| RC522 MOSI | D23 | GPIO 23 |
| RC522 MISO | D19 | GPIO 19 |
| RC522 RST | D27 | GPIO 27 |
| LCD RS | D32 | GPIO 32 |
| LCD E | D25 | GPIO 25 |
| LCD D4 | D22 | GPIO 22 |
| LCD D5 | D21 | GPIO 21 |
| LCD D6 | RX2 | GPIO 16 |
| LCD D7 | TX2 | GPIO 17 |
| Yeşil LED | D26 | GPIO 26 |
| Kırmızı LED | D33 | GPIO 33 |
| Buzzer kontrolü | D14 | GPIO 14 |

`VN`, VIN değildir. `VN/GPIO39` bu montajda kullanılmayacaktır.

## 4. Jak soketi ve ana güç girişi

Üç bacaklı jak soketinde genellikle `+5V`, `GND` ve anahtarlı yardımcı bacak
bulunur. Fiziksel bacak yerleri soket modeline göre değişebileceği için görünüşe
bakarak tahmin etme. Multimetreyle belirlenmiş `+5V` ve `GND` bacaklarını kullan;
üçüncü anahtarlı bacağı boş ve izole bırak.

```text
Jak +5V  -> Devre +5V dağıtım hattı
Jak GND  -> Devre ORTAK GND hattı
3. bacak -> BAĞLANMAYACAK
```

ESP32 güç bağlantısı:

```text
Jak +5V -> ESP32 VIN
Jak GND -> ESP32 GND
```

ESP32 üzerindeki iki GND pini içeride ortaktır. Birisi adaptör GND için, diğeri
ortak GND dağıtımı için kullanılabilir.

## 5. 5V ve ortak GND dağıtımı

### +5V hattına bağlanacaklar

```text
Jak +5V
  |-- ESP32 VIN
  |-- LCD VDD (pin 2)
  |-- LCD A (pin 15, mevcut çalışan dirençli bağlantı üzerinden)
  |-- Buzzer +
  |-- 470 uF kondansatör +
  `-- 100 nF kondansatörün bir bacağı
```

### Ortak GND hattına bağlanacaklar

```text
Jak GND
  |-- ESP32 GND
  |-- RC522 GND
  |-- LCD VSS (pin 1)
  |-- LCD V0 (pin 3, potansiyometre yoksa)
  |-- LCD RW (pin 5)
  |-- LCD K (pin 16)
  |-- Yeşil LED'in 220 ohm direnç sonrası ucu
  |-- Kırmızı LED'in 220 ohm direnç sonrası ucu
  |-- BC337 EMITTER
  |-- 470 uF kondansatör -
  `-- 100 nF kondansatörün diğer bacağı
```

## 6. Kondansatör bağlantıları

Kondansatörler güç hattına **paralel** bağlanır; besleme kablosuna seri bağlanmaz.
Jak girişine ve ESP32'ye yakın yerleştirilmelidir.

### 470 uF / 16V elektrolitik kondansatör

```text
Kondansatör + -> +5V hattı
Kondansatör - -> ORTAK GND
```

Gövde üzerindeki şerit genellikle eksi bacağı gösterir. Ters bağlantı
kondansatörün ısınmasına, şişmesine veya patlamasına neden olabilir.

### 100 nF seramik kondansatör

```text
Bir bacak   -> +5V hattı
Diğer bacak -> ORTAK GND
```

100 nF seramik kondansatör kutupsuzdur; iki bacağın yönü önemli değildir.

## 7. RC522 bağlantıları

| RC522 pini | Bağlanacağı yer |
| --- | --- |
| SDA / SS | ESP32 D5 / GPIO5 |
| SCK | ESP32 D18 / GPIO18 |
| MOSI | ESP32 D23 / GPIO23 |
| MISO | ESP32 D19 / GPIO19 |
| RST | ESP32 D27 / GPIO27 |
| 3.3V | ESP32 3V3 |
| GND | ORTAK GND |

RC522 üzerindeki `SDA` pini bu bağlantıda SPI `SS` görevi görür; LCD bağlantısıyla
ilgili değildir.

## 8. 2x16 paralel LCD bağlantıları

LCD, I2C dönüştürücü olmadan 4-bit modda kullanılır.

| LCD no | LCD pini | Bağlanacağı yer |
| ---: | --- | --- |
| 1 | VSS | ORTAK GND |
| 2 | VDD | +5V |
| 3 | V0 | Potansiyometre yoksa GND |
| 4 | RS | ESP32 D32 / GPIO32 |
| 5 | RW | GND |
| 6 | E | ESP32 D25 / GPIO25 |
| 7 | D0 | Bağlanmayacak |
| 8 | D1 | Bağlanmayacak |
| 9 | D2 | Bağlanmayacak |
| 10 | D3 | Bağlanmayacak |
| 11 | D4 | ESP32 D22 / GPIO22 |
| 12 | D5 | ESP32 D21 / GPIO21 |
| 13 | D6 | ESP32 RX2 / GPIO16 |
| 14 | D7 | ESP32 TX2 / GPIO17 |
| 15 | A | +5V, mevcut çalışan dirençli bağlantı üzerinden |
| 16 | K | GND |

LCD `D0`, `D1`, `D2` ve `D3` pinleri boş bırakılmalıdır. LCD arka aydınlatması
daha önce mevcut bağlantıyla çalıştıysa `A` ve `K` bağlantısı aynen korunmalıdır.

## 9. Yeşil ve kırmızı LED bağlantıları

Her LED için ayrı bir `220 ohm` direnç kullanılmalıdır.

Yeşil LED:

```text
ESP32 D26 / GPIO26 -> Yeşil LED uzun bacak / anot (+)
Yeşil LED kısa bacak / katot (-) -> 220 ohm -> ORTAK GND
```

Kırmızı LED:

```text
ESP32 D33 / GPIO33 -> Kırmızı LED uzun bacak / anot (+)
Kırmızı LED kısa bacak / katot (-) -> 220 ohm -> ORTAK GND
```

Direnç LED'in anot veya katot tarafında olabilir; önemli olan LED ile seri olmasıdır.

## 10. BC337 transistörlü buzzer bağlantısı

Bu montajda ESP32 buzzerı doğrudan beslemez. GPIO14 yalnızca BC337'yi kontrol
eder; buzzer enerjisini adaptörün 5V hattından alır.

```text
ESP32 D14 / GPIO14 -> 1K ohm direnç -> BC337 BASE
BC337 EMITTER       -> ORTAK GND
BC337 COLLECTOR     -> Buzzer -
Buzzer +            -> +5V hattı
```

`1K ohm` direnç olmadan GPIO14'ü BC337 BASE bacağına bağlama.

BC337 üzerinde şu üç uç bulunur:

- `B`: Base — 1K direnç üzerinden GPIO14'e gider.
- `C`: Collector — buzzer eksi ucuna gider.
- `E`: Emitter — ortak GND'ye gider.

BC337'nin fiziksel bacak sırası üreticiye göre doğrulanmalıdır. Düz yüzüne bakıp
tahmin etme; parçanın veri sayfasını veya multimetrenin transistör testini kullan.

Manyetik/bobinli buzzer kullanılıyorsa buzzer uçlarına ters koruma diyodu ekle:

```text
Diyot çizgili uç -> Buzzer + / +5V
Diyot diğer uç   -> Buzzer - / BC337 COLLECTOR
```

Aktif piezo buzzerda bu diyot genellikle gerekmez. Buzzer tipi bilinmiyorsa enerji
vermeden önce üzerindeki model/gerilim bilgisini kontrol et.

## 11. Enerji vermeden önce son kontrol

1. Adaptörü prizden çıkar.
2. Jak soketinin üçüncü anahtarlı bacağının boş olduğunu kontrol et.
3. Multimetreyle `+5V` ve `GND` arasında doğrudan kısa devre olmadığını kontrol et.
4. 470 uF kondansatörün `+` ucunun 5V'a, `-` ucunun GND'ye gittiğini kontrol et.
5. RC522 beslemesinin ESP32 `3V3` pinine gittiğini kontrol et.
6. LCD `RW`, `VSS`, `V0` ve `K` bağlantılarını kontrol et.
7. Her LED'de ayrı 220 ohm direnç olduğunu kontrol et.
8. GPIO14 ile BC337 BASE arasında 1K direnç olduğunu kontrol et.
9. BC337 EMITTER ucunun GND'ye, COLLECTOR ucunun buzzer eksiye gittiğini kontrol et.
10. Buzzer artı ucunun 5V'a gittiğini kontrol et.

## 12. İlk çalıştırma sırası

1. ESP32, RC522, LCD ve buzzerı mümkünse soketlerinden çıkar.
2. Yalnızca jak, klemens ve kondansatörleri bağla.
3. Adaptörü tak ve dağıtım hattında yaklaşık `5V DC` ölç.
4. Gücü kes; ESP32'yi tak ve yeniden enerji ver.
5. Gücü tekrar kes; LCD'yi tak ve çalışmasını kontrol et.
6. Gücü tekrar kes; RC522'yi tak ve kart okut.
7. LED'leri kontrol et.
8. En son BC337 ve buzzer devresini bağla.

ESP32 rastgele yeniden başlar, LCD ışığı titreşir, buzzer çalınca cihaz kapanır
veya Seri Monitör'de `Brownout detector` görülürse 5V/1A adaptör yetersiz ya da
kablo bağlantısı zayıf olabilir. Bu durumda kaliteli regüle 5V/2A adaptör kullan.

## 13. Çalışma doğrulaması

- Açılışta LCD'de başlatma ve Wi-Fi mesajları görünür.
- Bağlantıdan sonra LCD'de `Kart bekleniyor` görünür.
- Başarılı kartta yeşil LED yanar ve buzzer iki kısa ses verir.
- Hatalı veya tanımsız kartta kırmızı LED yanar ve buzzer iki uzun ses verir.
- RFID kart ID değeri için Arduino IDE Seri Monitör `115200` baud hızında açılır;
  `RFID kart:` satırındaki değer başındaki sıfırlar dahil aynen personele kaydedilir.

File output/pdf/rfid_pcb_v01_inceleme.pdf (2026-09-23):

# V4 / PCB mekanik kontrolü

V0.1 - %100 gerçek boyut - Sayfaya sığdırma KAPALI - Üretim maskesi değildir

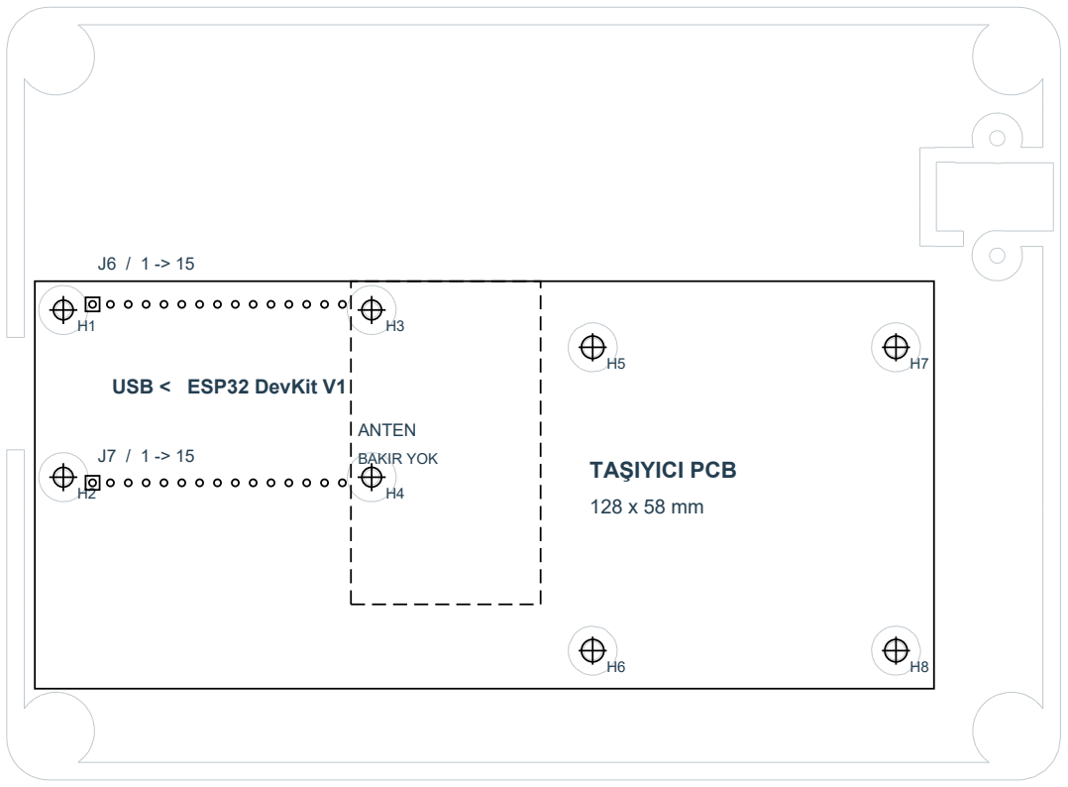
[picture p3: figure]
USB < ESP32 DevKit V1; TAŞIYICI PCB; ANTEN; BAKIR YOK

Gri: V4 gövde STL kesiti. Siyah: PCB sınırı, delikler ve ESP32 soketleri.

Bu çizgi cetvelle TAM 50 mm olmalı.

1. Önce 50 mm çizgisini ölçün; çıktı ölçekli değilse parçalarla karşılaştırmayın.
2. Kartı/şablonu V4 içindeki sekiz vida ayağına hizalayın. Gri çerçeve 150 x 110 mm.
3. ESP32 iki pin sırası için 25,40 mm VARSAYILDI; gerçek kartla doğrulayın.
4. Pin adımı 2,54 mm. USB solda. J6 pin 1=VIN; J7 pin 1=3V3.
5. PCB altı Z=10 mm, üstü Z=11,6 mm. Soket yüksekliği ayrıca eklenir.
6. USB açıklığı ve fiş gövdesi soket yüksekliğiyle birlikte kontrol edilmelidir.
7. Kapağın arkasındaki ekran/okuyucu için bu karta doğrudan geçme varsayılmadı.

BU DOSYA ÜRETİME HAZIR BİR PCB DEĞİLDİR.

Yollar, KiCad ERC/DRC, gerçek parça ölçüleri ve montaj testi henüz tamamlanmadı.

RFID Personel / donanım V0.1 | 1 / 3

# Devre ve bağlantı özeti

Mevcut GPIO eşlemesi korunur. Geliştirme kartı soketten sökülüp değiştirilebilir.

GÜÇ: J1 -> F1 -> +5V

+5V -> LCD / SN74AHCT244 / buzzer. JP1 üzerinden ESP32 VIN.
ESP32 3V3 -> RC522. Bütün GND hatları ortaktır. Yalnızca regüle 5V giriş.

ESP32 / hazır DevKit V1

LCD: GPIO32, 25, 22, 21, 16, 17 RFID: SS=5; RST=27
SCK=18; MOSI=23; MISO=19
Yeşil=26; kırmızı=33; buzzer=14 J6/J7: iki adet 1x15 dişi soket

U1 -> J3 / paralel LCD

SN74AHCT244N: 3,3V -> 5V
RN1: altı girişe 10k pull-down RW=GND; D0-D3 bağlanmaz
RV1: kontrast; R5: arka ışık 16 pin şerit kablo; 12 aktif hat

J2 / RC522

3,3V besleme, 5V bağlanmaz. R7/R8: SCK/MOSI üzerinde 33R R6: SS üzerinde 10k pull-up IRQ boş; kablo isimle eşlenir.

J4 / LED ve J5 / buzzer

LED başına kart üzerinde 220R GPIO14 -> 1k -> BC337 base Emitter=GND, collector=buzzer -D1 katodu +5V; R4=100k B-E

## Parça seçimi / kontrol bekleyenler

DevKit sıra aralığı, soket yüksekliği ve pin etiketleri; USB fişinin kutuya erişimi.

Konnektör modelleri, C1 çapı/pin aralığı, BC337 bacak sırası, RV1 sürgü pini.

Buzzer akımı, LCD arka ışık akımı ve besleme düşümü; F1 son seçimi.

PCB anten boşluğu, kapak altındaki kablo payı ve kapalı kutuda RF testi.

## İlk montajda besleme kuralı

USB ve harici 5V aynı anda bağlanmaz; JP1 bir güç seçme devresi değildir.

İlk denemede programlamak için ESP32 soketten çıkarılır. Güç kesikken takılır.

Bu taslakta ters polarite koruması ve 9/12V düşürücü bulunmaz.

Teknik dayanaklar: proje firmware/bağlantı belgesi; TI AHCT244;

onsemi BC337; Bourns MF-R; Espressif yerleşim kılavuzu. Linkler README.md içinde.

Şema ve yerleşim ayrı dosyalarda düzenlenebilir. | 2 / 3

# V0.1 / pin düzeyinde devre şeması

Aynı isimli hatlar bağlıdır. NC bağlanmaz. İşlevsel kutular fiziksel pin sırasını göstermez; numaralar esas alınır.

J6
DevKit V1 socket 1x15
ESP_VIN | 1 VIN
GND | 2 GND
NC | 3 GPIO13
NC | 4 GPIO12
GPIO14 | 5 GPIO14
GPIO27 | 6 GPIO27
GPIO26 | 7 GPIO26
GPIO25 | 8 GPIO25
GPIO33 9 | GPIO33
GPIO32 10 | GPIO32
GPIO35 11 | NC
GPIO34 12 | NC
GPIO39 13 | NC
GPIO36 14 | NC
EN 15 | NC

J7
DevKit V1 socket 1x15
+3V3 | 1 3V3
GND | 2 GND
NC | 3 GPIO15
NC | 4 GPIO2
NC | 5 GPIO4
GPIO16 | 6 GPIO16
GPIO17 | 7 GPIO17
GPIO5 | 8 GPIO5
GPIO18 9 | GPIO18
GPIO19 10 | GPIO19
GPIO21 11 | GPIO21
GPIO3 12 | NC
GPIO1 13 | NC
GPIO22 14 | GPIO22
GPIO23 15 | GPIO23

J1
5V DC INPUT
+5V_IN | 1 +5V_IN | GND 2 | GND

F1
MF-R075 0.75A
+5V_IN | 1 1 | 2 2 | +5V

JP1
ESP VIN LINK
+5V | 1 5V | VIN 2 | ESP_VIN

J2
RC522
GPIO5 | 1 SS
RFID_SCK | 2 SCK
RFID_MOSI | 3 MOSI
GPIO19 | 4 MISO
IRQ 5 | NC
GND 6 | GND
RST 7 | GPIO27
3V3 8 | +3V3

J3
LCD1602 PARALLEL
GND | 1 VSS
+5V | 2 VDD
LCD_VO | 3 VO
LCD_RS_5V | 4 RS
GND | 5 RW
LCD_E_5V | 6 E
NC | 7 D0
NC | 8 D1
D2 9 | NC
D3 10 | NC
D4 11 | LCD_D4_5V
D5 12 | LCD_D5_5V
D6 13 | LCD_D6_5V
D7 14 | LCD_D7_5V
A 15 | LCD_A
K 16 | GND

J4
STATUS LEDs
GREEN_A | 1 GREEN_A
GND | 2 GREEN_K
RED_A 3 | RED_A
RED_K 4 | GND

J5
5V ACTIVE BUZZER
+5V | 1 PLUS | MINUS 2 | BUZZ_NEG

U1
SN74AHCT244N
GND | 1 1OE
GPIO32 | 2 1A1
NC | 3 2Y4
GPIO25 | 4 1A2
NC | 5 2Y3
GPIO22 | 6 1A3
LCD_D7_5V | 7 2Y2
GPIO21 | 8 1A4
LCD_D6_5V | 9 2Y1
GND | 10 GND
2A1 11 | GPIO16
1Y4 12 | LCD_D5_5V
2A2 13 | GPIO17
1Y3 14 | LCD_D4_5V
2A3 15 | GND
1Y2 16 | LCD_E_5V
2A4 17 | GND
1Y1 18 | LCD_RS_5V
2OE 19 | GND
VCC 20 | +5V

RN1
8x10k BUSSED
GND | 1 COMMON
GPIO32 | 2 R1
GPIO25 | 3 R2
GPIO22 | 4 R3
GPIO21 | 5 R4
R5 6 | GPIO16
R6 7 | GPIO17
R7 8 | NC
R8 9 | NC

R1
220R
GPIO26 | 1 1 | 2 2 | GREEN_A

R2
220R
GPIO33 | 1 1 | 2 2 | RED_A

R3
1k
GPIO14 | 1 1 | 2 2 | BUZZ_BASE

R4
100k
BUZZ_BASE | 1 1 | 2 2 | GND

R5
330R INITIAL
+5V | 1 1 | 2 2 | LCD_A

R6
10k
+3V3 | 1 1 | 2 2 | GPIO5

R7
33R
GPIO18 | 1 1 | 2 2 | RFID_SCK

R8
33R
GPIO23 | 1 1 | 2 2 | RFID_MOSI

Q1
BC337-40
BUZZ_NEG | 1 C
BUZZ_BASE | 2 B
E 3 | GND

D1
1N4148
+5V | 1 K | A 2 | BUZZ_NEG

C1
470uF 16V
+5V | 1 + | - 2 | GND

C2
100nF
+5V | 1 1 | 2 2 | GND

C3
100nF
+5V | 1 1 | 2 2 | GND

C4
100nF
+3V3 | 1 1 | 2 2 | GND

C5
10uF 10V
+3V3 | 1 + | - 2 | GND

C6
100nF
ESP_VIN | 1 1 | 2 2 | GND

C7
10uF 10V
+3V3 | 1 + | - 2 | GND

RV1
10k CONTRAST
GND | 1 LOW
LCD_VO | 2 WIPER
HIGH 3 | +5V

TP1
+5V
+5V | 1 +5V

TP2
+3V3
+3V3 | 1 +3V3

TP3
GND
GND | 1 GND
Kaynak: design.json / bağlantı etiketleri. KiCad ERC/DRC ve bakır yönlendirme tamamlanmadı. | 3 / 3

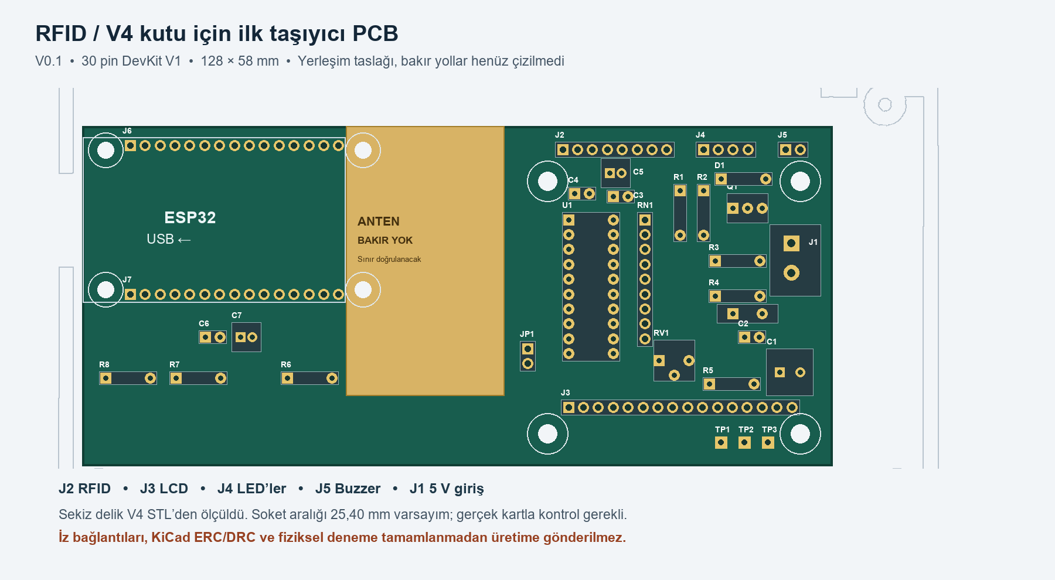
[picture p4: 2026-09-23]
hardware/pcb-v1/pcb_yerlesim.png

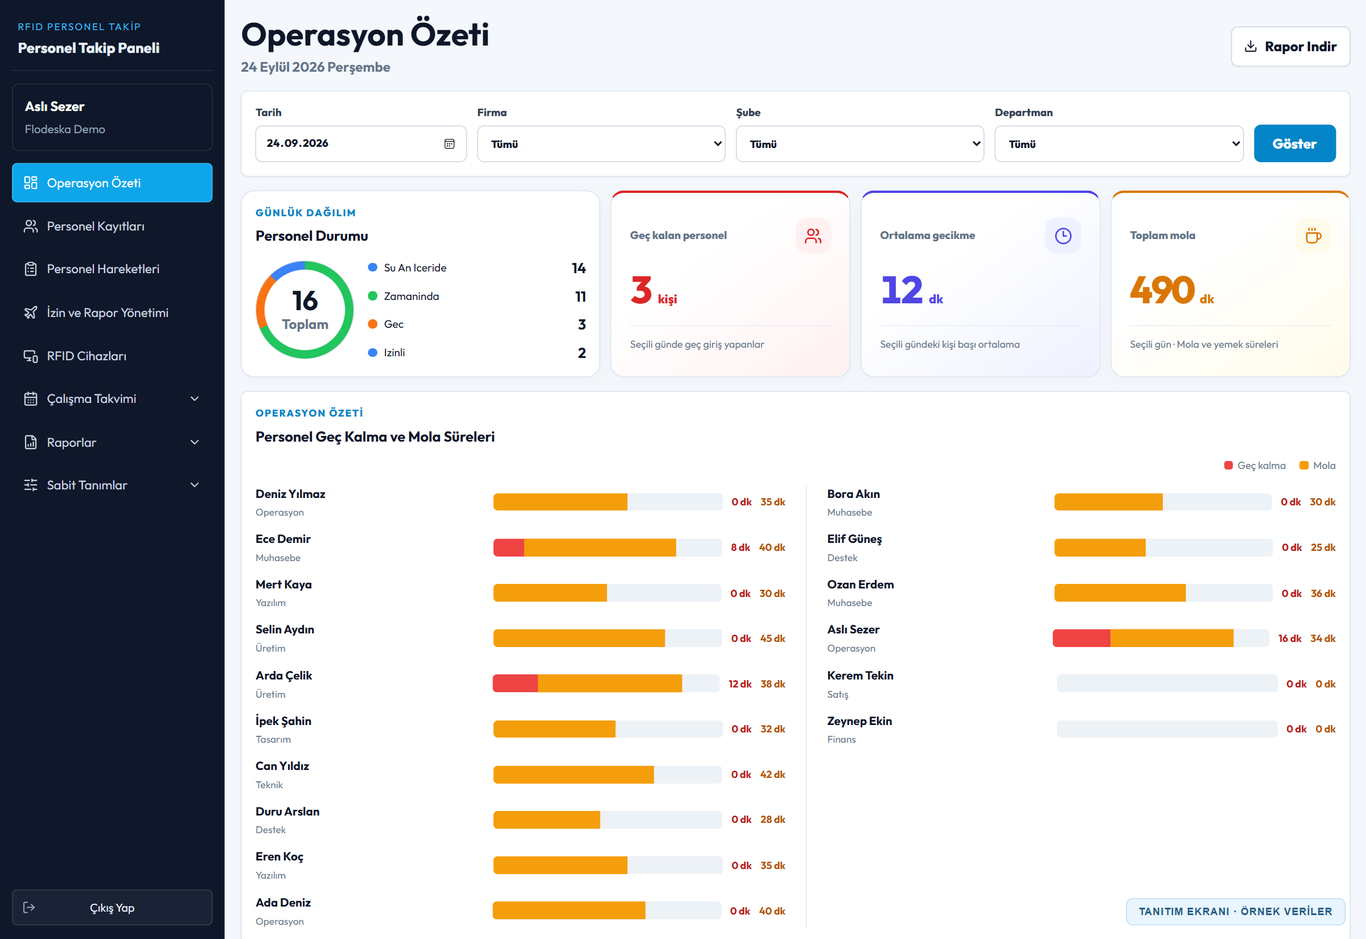
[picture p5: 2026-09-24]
public/images/marketing/flodeska-operasyon-ozeti-demo.png

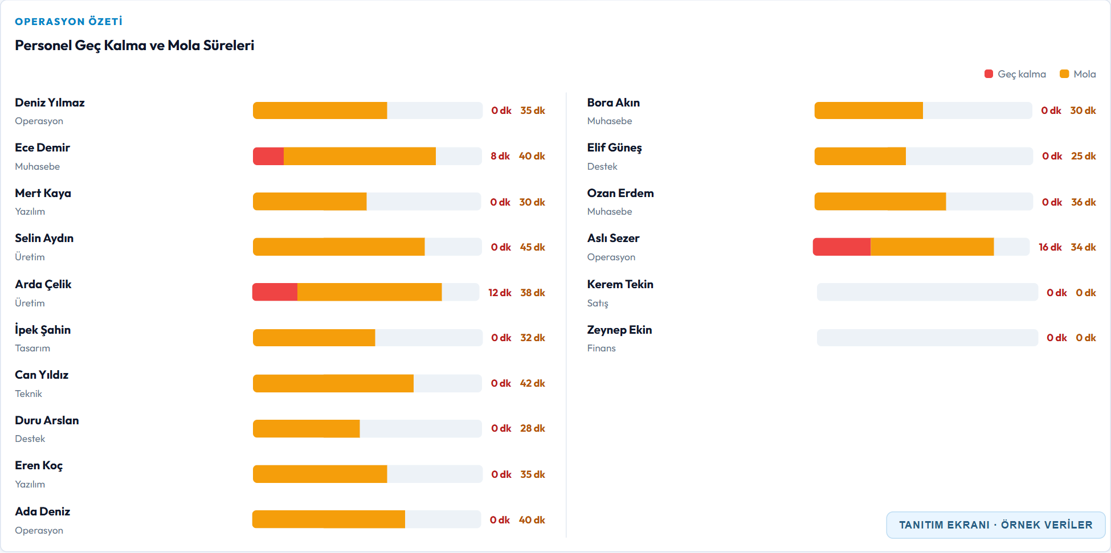
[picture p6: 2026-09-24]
public/images/marketing/flodeska-personel-grafikleri-demo.png

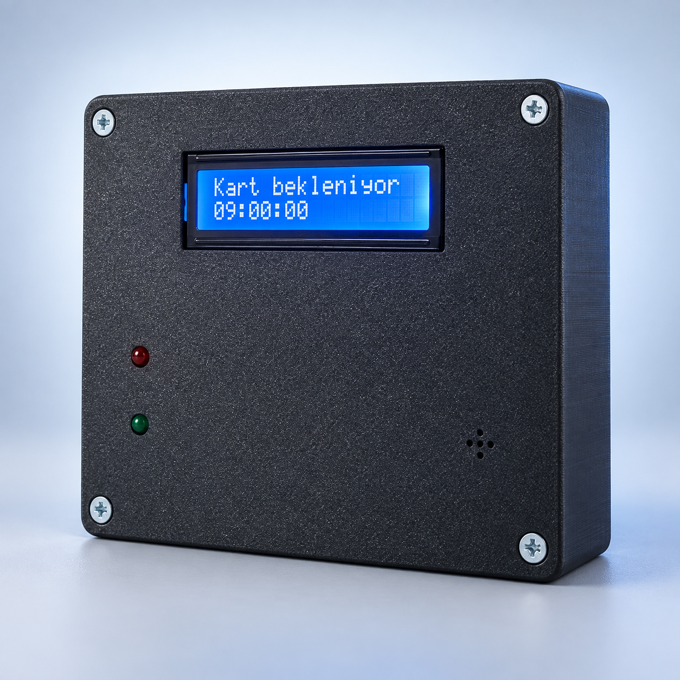
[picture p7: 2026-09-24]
UrunGorsel/Tanitim/flodeska-urun-studyosu-v1.png

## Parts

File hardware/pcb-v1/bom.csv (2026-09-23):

Reference | Qty | Value | Footprint | Notes
J6 | 1 | DevKit V1 socket 1x15 | J6_Header_15_P2.54_H | ASSUMED 25.40 mm row spacing; 2.54 mm pitch. Confirm labels and orientation on actual board.
J7 | 1 | DevKit V1 socket 1x15 | J7_Header_15_P2.54_H | ASSUMED 25.40 mm row spacing; 2.54 mm pitch. Confirm labels and orientation on actual board.
J1 | 1 | 5V DC INPUT | J1_Header_2_P5.08_V | 2-pin 5.08 mm terminal block; body envelope provisional; regulated 5V only, no reverse-polarity protection.
F1 | 1 | MF-R075 0.75A | F1_PTC_P5.08_H | Bourns MF-R075 nominal 5.1 mm leads; current/temperature derating and voltage drop need measurement.
JP1 | 1 | ESP VIN LINK | JP1_Header_2_P2.54_V | Fit shunt for normal external power. Not a USB power multiplexer; program removed module for first bring-up.
J2 | 1 | RC522 | J2_Header_8_P2.54_H | Match signal NAMES on reader, not cable colours. 3.3V only; IRQ unused.
J3 | 1 | LCD1602 PARALLEL | J3_Header_16_P2.54_H | 16-pin ribbon cable. Pin 1 at LEFT in this PCB view. LCD backlight must remain current limited.
J4 | 1 | STATUS LEDs | J4_Header_4_P2.54_H
J5 | 1 | 5V ACTIVE BUZZER | J5_Header_2_P2.54_H
U1 | 1 | SN74AHCT244N | U1_DIP20_W7.62 | Use AHCT or separately verified HCT; ordinary HC at 5V is not an equivalent 3.3V-input replacement. Both OE pins grounded.
RN1 | 1 | 8x10k BUSSED | RN1_Header_9_P2.54_V | SIP-9, eight resistors sharing pin 1. NOT an isolated network. Spare pins 8/9 unconnected.
R1 | 1 | 220R | R1_R_P7.62_V
R2 | 1 | 220R | R2_R_P7.62_V
R3 | 1 | 1k | R3_R_P7.62_H
R4 | 1 | 100k | R4_R_P7.62_H
R5 | 1 | 330R INITIAL | R5_R_P7.62_H | Safe dim starting value, adjust ONLY from backlight specifications/measured current. Never blindly bridge.
R6 | 1 | 10k | R6_R_P7.62_H | SS idle high; boot-strapping GPIO5 must remain compatible with actual DevKit.
R7 | 1 | 33R | R7_R_P7.62_H | SPI clock series damping; verify waveforms/read reliability after routing.
R8 | 1 | 33R | R8_R_P7.62_H | SPI MOSI series damping; keep RC522 harness short.
Q1 | 1 | BC337-40 | Q1_TO92_CBE_FORMED_P2.54 | onsemi C-B-E reference; formed 2.54 mm leads, check actual transistor. 1k base resistor assumes a small buzzer; measure current.
D1 | 1 | 1N4148 | D1_D_P7.62_H | Pin 1=CATHODE, stripe at +5V; pin 2=ANODE at buzzer negative. Verify rating for actual buzzer.
C1 | 1 | 470uF 16V | C1_CP_P3.5_H | Radial electrolytic, assumed diameter 8 mm and lead pitch 3.5 mm. Check actual part and polarity.
C2 | 1 | 100nF | C2_C_P2.54_H
C3 | 1 | 100nF | C3_C_P2.54_H
C4 | 1 | 100nF | C4_C_P2.54_H
C5 | 1 | 10uF 10V | C5_CP_P2_H | Radial electrolytic, assumed diameter 5 mm and lead pitch 2 mm. Check actual part and polarity.
C6 | 1 | 100nF | C6_C_P2.54_H
C7 | 1 | 10uF 10V | C7_CP_P2_H | Radial electrolytic, assumed diameter 5 mm and lead pitch 2 mm. Check actual part and polarity.
RV1 | 1 | 10k CONTRAST | RV1_Trimmer_3pin_5.08x2.54 | Provisional trimmer footprint, verify model AND wiper pin before order.
TP1 | 1 | +5V | TP1_TestPoint_THT
TP2 | 1 | +3V3 | TP2_TestPoint_THT
TP3 | 1 | GND | TP3_TestPoint_THT

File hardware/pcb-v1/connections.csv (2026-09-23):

Reference | Pin | Signal | Net | X_mm | Y_mm
J6 | 1 | VIN | ESP_VIN | 12.22 | 42.3
J6 | 2 | GND | GND | 14.760000000000002 | 42.3
J6 | 3 | GPIO13 | NC | 17.3 | 42.3
J6 | 4 | GPIO12 | NC | 19.84 | 42.3
J6 | 5 | GPIO14 | GPIO14 | 22.380000000000003 | 42.3
J6 | 6 | GPIO27 | GPIO27 | 24.92 | 42.3
J6 | 7 | GPIO26 | GPIO26 | 27.46 | 42.3
J6 | 8 | GPIO25 | GPIO25 | 30.0 | 42.3
J6 | 9 | GPIO33 | GPIO33 | 32.54 | 42.3
J6 | 10 | GPIO32 | GPIO32 | 35.08 | 42.3
J6 | 11 | GPIO35 | NC | 37.62 | 42.3
J6 | 12 | GPIO34 | NC | 40.160000000000004 | 42.3
J6 | 13 | GPIO39 | NC | 42.7 | 42.3
J6 | 14 | GPIO36 | NC | 45.24 | 42.3
J6 | 15 | EN | NC | 47.78 | 42.3
J7 | 1 | 3V3 | +3V3 | 12.22 | 67.7
J7 | 2 | GND | GND | 14.760000000000002 | 67.7
J7 | 3 | GPIO15 | NC | 17.3 | 67.7
J7 | 4 | GPIO2 | NC | 19.84 | 67.7
J7 | 5 | GPIO4 | NC | 22.380000000000003 | 67.7
J7 | 6 | GPIO16 | GPIO16 | 24.92 | 67.7
J7 | 7 | GPIO17 | GPIO17 | 27.46 | 67.7
J7 | 8 | GPIO5 | GPIO5 | 30.0 | 67.7
J7 | 9 | GPIO18 | GPIO18 | 32.54 | 67.7
J7 | 10 | GPIO19 | GPIO19 | 35.08 | 67.7
J7 | 11 | GPIO21 | GPIO21 | 37.62 | 67.7
J7 | 12 | GPIO3 | NC | 40.160000000000004 | 67.7
J7 | 13 | GPIO1 | NC | 42.7 | 67.7
J7 | 14 | GPIO22 | GPIO22 | 45.24 | 67.7
J7 | 15 | GPIO23 | GPIO23 | 47.78 | 67.7
J1 | 1 | +5V_IN | +5V_IN | 125 | 59.0
J1 | 2 | GND | GND | 125 | 64.08
F1 | 1 | 1 | +5V_IN | 115 | 71
F1 | 2 | 2 | +5V | 120.08 | 71
JP1 | 1 | 5V | +5V | 80 | 77.0
JP1 | 2 | VIN | ESP_VIN | 80 | 79.54
J2 | 1 | SS | GPIO5 | 86.0 | 43
J2 | 2 | SCK | RFID_SCK | 88.54 | 43
J2 | 3 | MOSI | RFID_MOSI | 91.08 | 43
J2 | 4 | MISO | GPIO19 | 93.62 | 43
J2 | 5 | IRQ | NC | 96.16 | 43
J2 | 6 | GND | GND | 98.7 | 43
J2 | 7 | RST | GPIO27 | 101.24 | 43
J2 | 8 | 3V3 | +3V3 | 103.78 | 43
J3 | 1 | VSS | GND | 87.0 | 87
J3 | 2 | VDD | +5V | 89.54 | 87
J3 | 3 | VO | LCD_VO | 92.08 | 87
J3 | 4 | RS | LCD_RS_5V | 94.62 | 87
J3 | 5 | RW | GND | 97.16 | 87
J3 | 6 | E | LCD_E_5V | 99.7 | 87
J3 | 7 | D0 | NC | 102.24 | 87
J3 | 8 | D1 | NC | 104.78 | 87
J3 | 9 | D2 | NC | 107.32 | 87
J3 | 10 | D3 | NC | 109.86 | 87
J3 | 11 | D4 | LCD_D4_5V | 112.4 | 87
J3 | 12 | D5 | LCD_D5_5V | 114.94 | 87
J3 | 13 | D6 | LCD_D6_5V | 117.48 | 87
J3 | 14 | D7 | LCD_D7_5V | 120.02000000000001 | 87
J3 | 15 | A | LCD_A | 122.56 | 87
J3 | 16 | K | GND | 125.1 | 87
J4 | 1 | GREEN_A | GREEN_A | 110.0 | 43
J4 | 2 | GREEN_K | GND | 112.54 | 43
J4 | 3 | RED_A | RED_A | 115.08 | 43
J4 | 4 | RED_K | GND | 117.62 | 43
J5 | 1 | PLUS | +5V | 124.0 | 43
J5 | 2 | MINUS | BUZZ_NEG | 126.54 | 43
U1 | 1 | 1OE | GND | 87 | 55.0
U1 | 2 | 1A1 | GPIO32 | 87 | 57.54
U1 | 3 | 2Y4 | NC | 87 | 60.08
U1 | 4 | 1A2 | GPIO25 | 87 | 62.62
U1 | 5 | 2Y3 | NC | 87 | 65.16
U1 | 6 | 1A3 | GPIO22 | 87 | 67.7
U1 | 7 | 2Y2 | LCD_D7_5V | 87 | 70.24
U1 | 8 | 1A4 | GPIO21 | 87 | 72.78
U1 | 9 | 2Y1 | LCD_D6_5V | 87 | 75.32
U1 | 10 | GND | GND | 87 | 77.86
U1 | 11 | 2A1 | GPIO16 | 94.62 | 77.86
U1 | 12 | 1Y4 | LCD_D5_5V | 94.62 | 75.32
U1 | 13 | 2A2 | GPIO17 | 94.62 | 72.78
U1 | 14 | 1Y3 | LCD_D4_5V | 94.62 | 70.24
U1 | 15 | 2A3 | GND | 94.62 | 67.7
U1 | 16 | 1Y2 | LCD_E_5V | 94.62 | 65.16
U1 | 17 | 2A4 | GND | 94.62 | 62.62
U1 | 18 | 1Y1 | LCD_RS_5V | 94.62 | 60.08
U1 | 19 | 2OE | GND | 94.62 | 57.54
U1 | 20 | VCC | +5V | 94.62 | 55.0
RN1 | 1 | COMMON | GND | 100 | 55.0
RN1 | 2 | R1 | GPIO32 | 100 | 57.54
RN1 | 3 | R2 | GPIO25 | 100 | 60.08
RN1 | 4 | R3 | GPIO22 | 100 | 62.62
RN1 | 5 | R4 | GPIO21 | 100 | 65.16
RN1 | 6 | R5 | GPIO16 | 100 | 67.7
RN1 | 7 | R6 | GPIO17 | 100 | 70.24
RN1 | 8 | R7 | NC | 100 | 72.78
RN1 | 9 | R8 | NC | 100 | 75.32
R1 | 1 | 1 | GPIO26 | 106 | 50
R1 | 2 | 2 | GREEN_A | 106 | 57.62
R2 | 1 | 1 | GPIO33 | 110 | 50
R2 | 2 | 2 | RED_A | 110 | 57.62
R3 | 1 | 1 | GPIO14 | 112 | 62
R3 | 2 | 2 | BUZZ_BASE | 119.62 | 62
R4 | 1 | 1 | BUZZ_BASE | 112 | 68
R4 | 2 | 2 | GND | 119.62 | 68
R5 | 1 | 1 | +5V | 111 | 83
R5 | 2 | 2 | LCD_A | 118.62 | 83
R6 | 1 | 1 | +3V3 | 39 | 82
R6 | 2 | 2 | GPIO5 | 46.62 | 82
R7 | 1 | 1 | GPIO18 | 20 | 82
R7 | 2 | 2 | RFID_SCK | 27.62 | 82
R8 | 1 | 1 | GPIO23 | 8 | 82
R8 | 2 | 2 | RFID_MOSI | 15.620000000000001 | 82
Q1 | 1 | C | BUZZ_NEG | 115 | 53
Q1 | 2 | B | BUZZ_BASE | 117.54 | 53
Q1 | 3 | E | GND | 120.08 | 53
D1 | 1 | K | +5V | 113 | 48
D1 | 2 | A | BUZZ_NEG | 120.62 | 48
C1 | 1 | + | +5V | 123 | 81
C1 | 2 | - | GND | 126.5 | 81
C2 | 1 | 1 | +5V | 117 | 75
C2 | 2 | 2 | GND | 119.54 | 75
C3 | 1 | 1 | +5V | 94.62 | 51
C3 | 2 | 2 | GND | 97.16000000000001 | 51
C4 | 1 | 1 | +3V3 | 88 | 50.5
C4 | 2 | 2 | GND | 90.54 | 50.5
C5 | 1 | + | +3V3 | 94 | 47
C5 | 2 | - | GND | 96 | 47
C6 | 1 | 1 | ESP_VIN | 25 | 75
C6 | 2 | 2 | GND | 27.54 | 75
C7 | 1 | + | +3V3 | 31 | 75
C7 | 2 | - | GND | 33 | 75
RV1 | 1 | LOW | GND | 102.46 | 79
RV1 | 2 | WIPER | LCD_VO | 105 | 81.54
RV1 | 3 | HIGH | +5V | 107.54 | 79
TP1 | 1 | +5V | +5V | 113 | 93
TP2 | 1 | +3V3 | +3V3 | 117 | 93
TP3 | 1 | GND | GND | 121 | 93

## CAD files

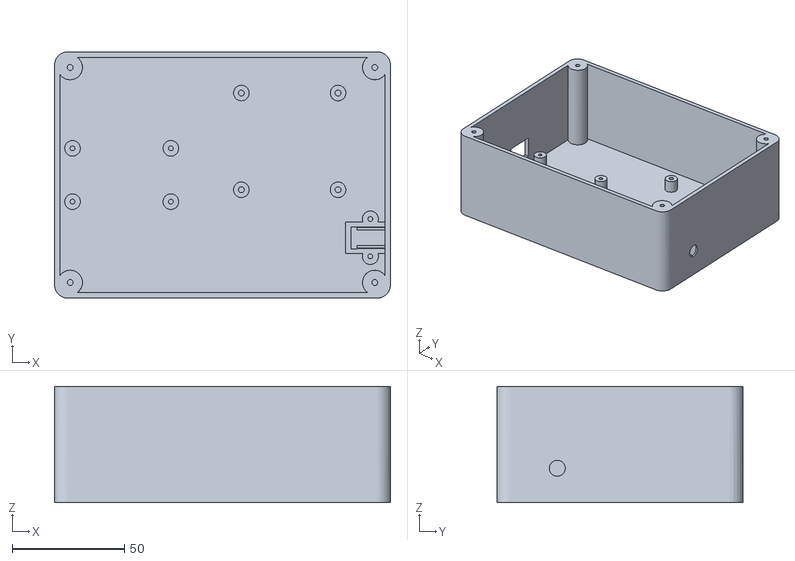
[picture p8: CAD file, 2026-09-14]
output/enclosure_v4/gövde.stl
150.0 x 110.0 x 52.0

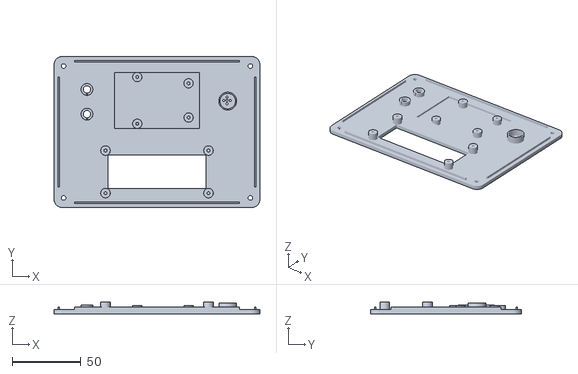
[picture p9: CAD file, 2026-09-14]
output/enclosure_v4/kapak.stl
150.0 x 110.0 x 8.50

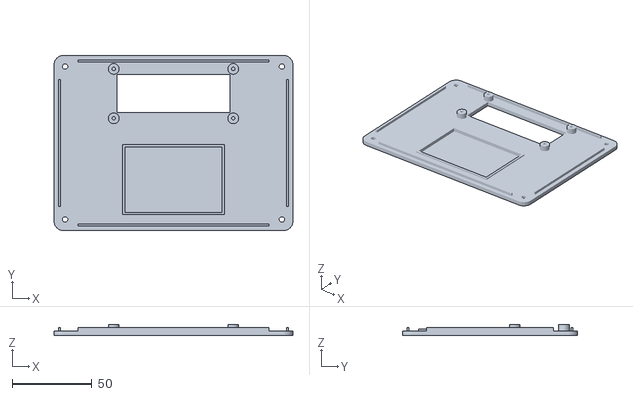
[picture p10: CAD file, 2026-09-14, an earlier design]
output/enclosure/kapak.stl
150.0 x 110.0 x 7.00

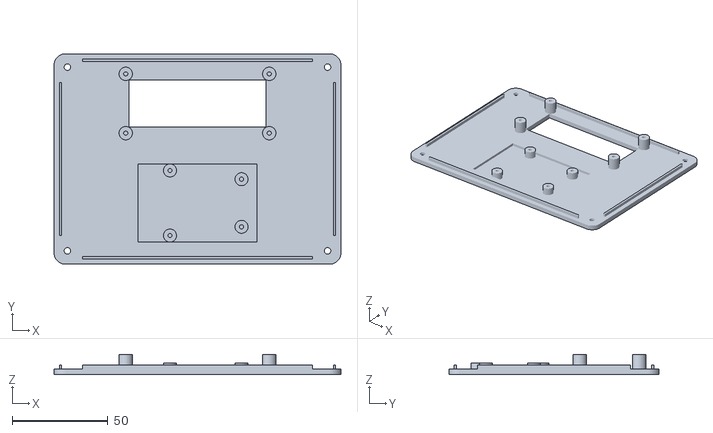
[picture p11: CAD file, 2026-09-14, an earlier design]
output/enclosure_v2/kapak_v2.stl
150.0 x 110.0 x 10.5

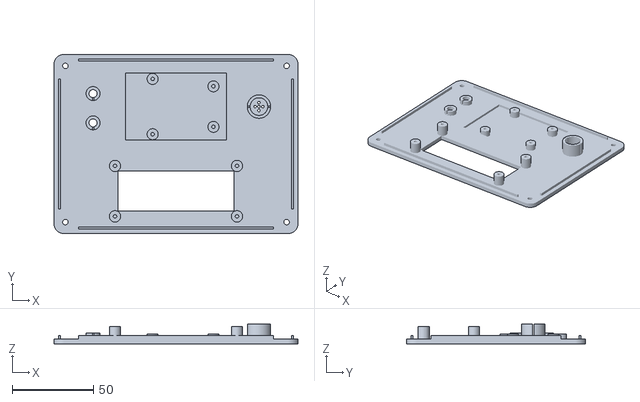
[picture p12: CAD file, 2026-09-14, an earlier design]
output/enclosure_v3/kapak_v3.stl
150.0 x 110.0 x 12.0

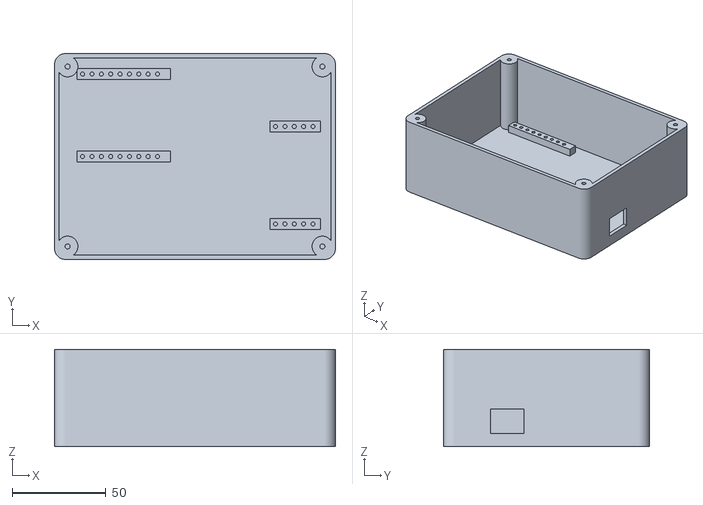
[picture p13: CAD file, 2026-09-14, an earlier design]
output/enclosure/govde.stl
150.0 x 110.0 x 52.0

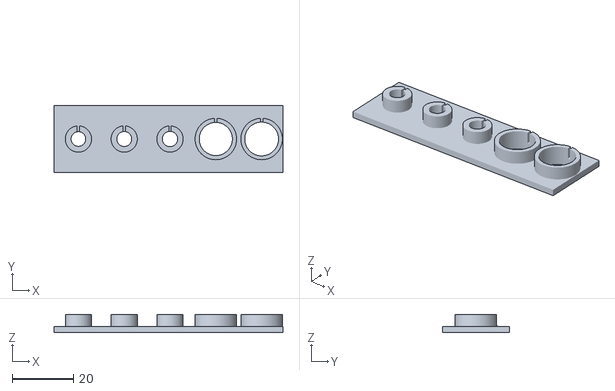
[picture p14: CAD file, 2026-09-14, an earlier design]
output/enclosure_v2/sikilik_testi.stl
75.0 x 22.0 x 6.00

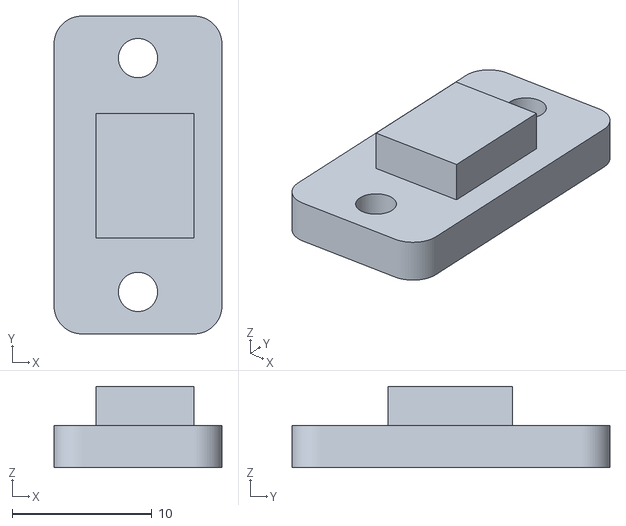
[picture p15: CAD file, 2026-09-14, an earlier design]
output/enclosure_v3/guc_jaki_baski_parcasi.stl
12.0 x 22.7 x 5.80

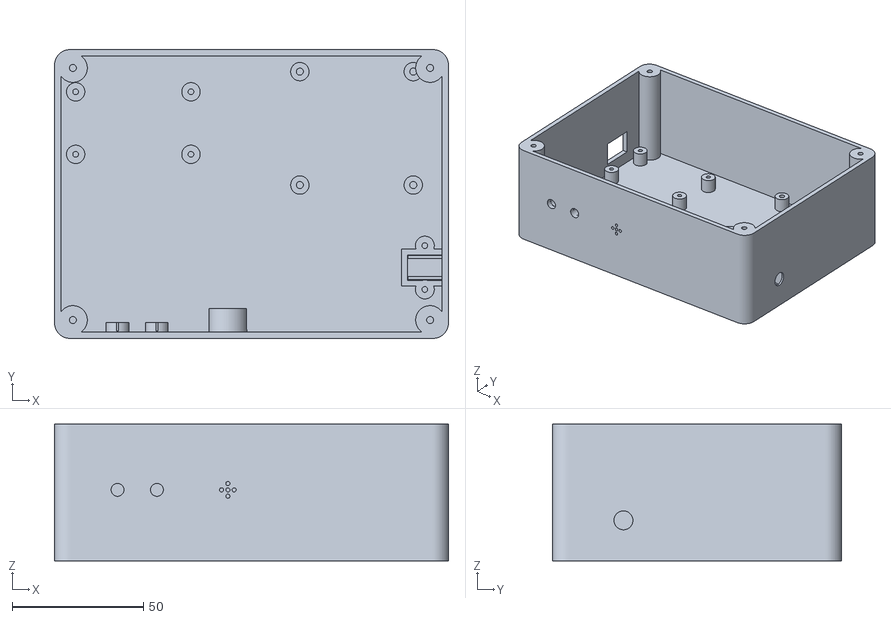
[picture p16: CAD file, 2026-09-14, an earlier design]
output/enclosure_v2/govde_v2.stl
150.0 x 110.0 x 52.0

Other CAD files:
output/enclosure_v3/govde_v3.stl
output/enclosure_v3/RFID_kutu_V3/govde_v3.stl

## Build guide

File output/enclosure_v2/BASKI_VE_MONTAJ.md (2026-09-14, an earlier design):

# RFID proje kutusu V2

Montajlı dış ölçü **150 × 110 × 55 mm**. Gövde 52 mm, kapak yüzeyi 3 mm; kapak ayakları kutunun içine girer. Tüm STL dosyaları **mm** birimindedir, %100 ölçekte dilimlenmelidir. Bu sürüm önceki kutuya ek parça değildir; V2 gövde ve V2 kapağı birlikte kullanın.

## Parçalar

| Dosya | Adet | Kullanım |
|---|---:|---|
| govde_v2.stl | 1 | ESP32 ve plaket için dört ayrı vida ayağı; iki LED, buzzer ve güç jakı yuvaları |
| kapak_v2.stl | 1 | LCD için dört vida ayağı ve pencere; RC522 için dört vida ayağı |
| guc_jaki_baski_parcasi.stl | 1 | Güç jakını üstten kapatan iki vidalı tutucu |
| sikilik_testi.stl | İsteğe bağlı 1 | LED ve buzzer için baskı toleransı testi |

## Esas alınan modüller

| Bileşen | Kullanılan ölçüler / yaklaşım |
|---|---|
| 1602 LCD | Winstar WH1602B tipi 80 × 36 mm PCB, 75 × 31 mm vida merkezleri; pencere 71,6 × 24,6 mm. PCB kapak içinden 7,5 mm uzakta. |
| RC522 | Joy-IT SBC-RFID-RC522 çizimi, 61,25 × 40 mm PCB; dört delik iki sırada, sıralar arası 37,39 mm, sıra enleri 34 ve 24,91 mm. Alt sıra kart kenarından 7,61 mm. Kart yatay çevrilmiştir. |
| ESP32 | 30 pinli DOIT DevKit V1, 51,8 × 28,2 mm PCB. Delik düzeni 43,9 × 23,8 mm. Enine ölçü, fiziksel ölçüm kaynağındaki 2,8 mm delik ve kenara 0,8 mm boşluktan hesaplanmıştır: 28,2 − 2 × (1,4 + 0,8). Kaynak üretici mekanik çizimi değildir; klonlar farklı olabilir. |
| Delikli plaket | 50 × 50 mm, 18 × 18 delik ve 2,54 mm adım esas alındı. İlk ve son delik merkezleri 17 × 2,54 = 43,18 mm. Dört köşe grid deliği M3 geçişi için 3,2 mm'ye genişletilir. Bu işlem boş veya köşelerinde devre bulunmayan plakette yapılır. |
| Güç jakı | Görsele benzeyen KLS DC-005A-2.5 modeli: gövde 14,4 mm uzunluk × 9 mm en × 11 mm yükseklik. Fotoğraftan kesin model teşhisi yapılamaz. |
| LED | 5 mm yuvarlak, örnek paket Kingbright WP7113; 4,9 mm yarıklı sıkıştırma bileziği ve 5,2 mm dış delik. |
| Buzzer | Kullanıcının verdiği 11 mm çap; SainSmart dokümanındaki 9 mm yüksek aktif buzzer esas alındı. Yuva arkası açıktır, sıkıştırma çapı 10,85 mm. |

**Bütün modüller için tek bir evrensel standart yoktur.** Kullanıcının isteğiyle yukarıdaki kaynak varyantları seçildi. Fiziksel baskı ve kullanıcının parçalarıyla montaj denenmedi. Kaynak dosyası `olculer.json` içindeki boyutlar değiştirilebilir; ardından `uret.py` çalıştırılarak STL'ler yeniden üretilir. RC522'nin dört delik koordinatı `hole_offsets` içindedir; `holes` alanı bu kart için yalnızca çizim açıklamasıdır.

## Yerleşim ve montaj

1. **ESP32:** Gövdenin sol arka bölümündeki dört ayağa takılır. Micro USB konektörü sol duvara bakar; 16 × 12 mm servis açıklığı USB kablosu içindir. Kart PCB altı tabandan 10 mm yüksektedir. Kapak açıkken BOOT/EN düğmelerine erişilir.
2. **Plaket:** Sağ arka bölümde dört M3 vida ile sabitlenir. Lehim yüzeyi altında 7 mm boşluk vardır. Ayak çevresinde iletken yolları vida başına temas ettirmeyin; gerekirse yalıtkan pul kullanın.
3. **LED'ler:** Gövdenin ön duvarına içeriden yerleştirilir, kubbe dışarı bakar. Yarıklı bilezik gövdeyi sıkar; LED'in taban flanşı içeride kalır.
4. **Buzzer:** Ön duvardaki büyük yarıklı yuvaya içeriden bastırılır. Ses veren yüz beş delikli ızgaraya, bacaklar içeri bakar. Yuva duvarı esneyerek tutar.
5. **Güç jakı:** Sağ duvardaki yuvaya üstten yerleştirilir. Ağız dışa, lehim bacakları aşağı bakar. Altında 6 mm bacak/kablo boşluğu, yan terminal için kanal vardır. Ön duvardaki 1 mm omuz jakın dışarı çekilmesini, arka dayama içeri itilmesini sınırlar. Küçük baskı parçası üstten iki M2.5 vida ile kapatılır. Plastik üzerindeki 0,2 mm dikey pay gevşeklik bırakırsa ince yalıtkan bant şimiyle alınabilir; elektrik terminallerine baskı uygulamayın.
6. **LCD:** Ekran dışa bakacak şekilde kapağın arkasındaki dört ayağa vidalanır. I2C adaptörü ve kablolar içeride kalır.
7. **RC522:** Dört delikten kısa M2.5 vidalarla kapağa sabitlenir. Anten yüzü kapağa bakar. Anten önünde 1,4 mm plastik bırakılmıştır. Kartın montaj düzlemi ile ince panel arasında yaklaşık 4,6 mm vardır. Mümkünse plastik vidalar kullanın; montaj sonrası okuma mesafesini deneyin.
8. Kapak dört köşe vidasıyla kapatılır. Kapak kablolarına açılıp kapanmayı sağlayacak pay bırakın.

Vida başlangıç listesi: kapak için 4 × M3×12 havşa başlı; plaket için 4 × M3×6; ESP32 ve LCD için toplam 8 × M2.5×6; RC522 için 4 × M2.5×4; jak tutucusu için 2 × M2.5×8. Boylar yaklaşık 1,6 mm PCB ve pulsuz montaja göredir. Kısa vida tercih edin; vida kör deliğin tabanına dayanmamalıdır. M2.5 ayaklarında 2,2 mm, M3 ayaklarında 2,7 mm pilot delikler vardır; delikler basılı diş içermez. Uygun kılavuzla diş açın veya plastik için uygun vida kullanın.

## Baskı

- Gövde: tabanı tabla üzerinde, açık yüzü yukarı.
- Kapak: dış yüzü tabla üzerinde, ayaklar yukarı. Dosya zaten bu yöndedir.
- Jak baskı parçası: geniş düz yüz tabla üzerinde, küçük baskı çıkıntısı yukarı.
- Başlangıç ayarı: 0,4 mm nozül, 0,2 mm katman, 4 duvar, %20–25 dolgu. Malzeme profilini yazıcınıza göre seçin. Esneyen yuvalar için PETG tercih edilebilir.
- Gövdedeki yatay LED/buzzer yuvaları, jak kanalları ve USB açıklığı için **yerel destek gerekebilir**. Dilimleyicide destekleri inceleyin; küçük sıkıştırma yarıklarını destekle doldurmayın. Destekleri parçaları takmadan önce temizleyin.
- Kapak ve jak baskı parçası önerilen yönde destek gerektirmeyecek şekilde tasarlanmıştır.
- Önce `sikilik_testi.stl` basılabilir: soldan sağa LED çapları 4,8 / 4,9 / 5,0 mm; buzzer çapları 10,85 / 11,05 mm. Test parçasını düz yüzü altta kullanın. Gövdedeki yatay baskı yönü delik toleransını ayrıca etkileyebilir. Zorlayarak takmayın; gerekirse çapı kaynak dosyasında değiştirin.

## Kontroller ve sınırlar

STL'ler dışa aktarıldıktan sonra yeniden okunarak kapalı yüzey, tutarlı yüz yönü, pozitif hacim ve tek bağlı parça kontrollerinden geçirilmiştir. Gövde-kapak-jak tutucusu çakışmaları ve seçilen jak gövdesinin yuvaya oturması geometrik olarak kontrol edilmiştir. Örnek PCB/bileşen hacimleri birbirleriyle çakışmaz; bu kontrol gerçek kablo, lehim, tüm konektör ve her komponent ayrıntısını kapsamaz. Kutu dilimlenmedi veya fiziksel olarak basılmadı. Su/toz koruma sınıfı yoktur.

## Kaynaklar

- LCD: [Winstar WH1602B ürün sayfası](https://www.winstar.com.tw/products/lcd-display/character-lcd-display-module/lcd-display-16x2.html) ve [üretici ölçü çizimi](https://www.winstar.com.tw/uploads/files/7d640ef3cbbd07cb31ae8168e217d266.pdf).
- RC522: [Joy-IT ürün sayfası](https://joy-it.net/en/products/SBC-RFID-RC522), [Simac/Joy-IT mekanik çizimi](https://asset.conrad.com/media10/add/160267/c1/-/gl/001503746IN01/informacije-1503746-joy-it-sbc-rfid-rc522-rfid-komplet-1-kos.pdf).
- ESP32: [Fritzing topluluğunda kartın fiziksel ölçümü](https://forum.fritzing.org/t/doit-esp32-devkit-v1/6158/9). 23,8 mm enine vida aralığı kaynaktan yapılan hesaplamadır.
- Güç jakı: [KLS DC-005A-2.5-5A üretici teknik çizimi, Özdisan](https://img.ozdisan.com/ETicaret_Dosya/634768_165145.pdf).
- LED: [Kingbright delikli montaj LED katalog çizimleri](https://www.kingbrightusa.com/webimages/catalog/Through-HoleLED-P17-27.pdf).
- Buzzer: [SainSmart eğitim dokümanı](https://images-na.ssl-images-amazon.com/images/I/B1kzlYSfD4S.pdf); 11 mm çaplı aktif tip için 9 mm yükseklik açıklaması.
- Plaket: [Direnc.net 5×5 ürününde satıcının 18×18 delik açıklaması](https://www.direnc.net/5x5-delikli-plaket), [2,54 mm adımlı 5×5 plaket örneği](https://temperosystems.com.au/products/5-x-5cm-2-54-pitch-double-sided-universal-board/). 43,18 mm montaj aralığı tasarım hesabıdır; ayrı bir montaj standardı değildir.

Kaynaklar 10 Eylül 2026 tarihinde kontrol edildi.

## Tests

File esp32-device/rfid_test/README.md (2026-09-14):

# RC522 bagimsiz test

Bu test Wi-Fi, API ve LCD kullanmadan RC522 surumunu ve kart UID'sini Seri Monitor'e yazar. Ana uygulama dosyalari degismez; testi ESP32'ye yuklemek cihazdaki mevcut programin yerine gecer. Test bittiginde ana rfid_personel_device.ino programini tekrar yukle. Test kayitli Wi-Fi ayarlarini silmez.

## Yukleme

1. Harici adaptor baglantisini cikar, ESP32'yi USB ile bilgisayara bagla.
2. Arduino IDE'de bu klasordeki rfid_test.ino dosyasini ac.
3. Ana uygulamada kullandigin ESP32 kartini ve portunu sec.
4. Kutuphane Yoneticisi'nde MFRC522 (GithubCommunity / miguelbalboa) kutuphanesi kurulu olmali. Ana uygulama derleniyorsa zaten kurulu olabilir.
5. Yukle, Seri Monitor'u 115200 baud ac ve ESP32'nin EN/RESET dugmesine bas.
6. Daha once calisan karti veya RC522 ile gelen kart/anahtarligi antene yaklastir. Tekrar okutmak icin karti uzaklastirip getir.

LCD bu testte guncellenmez; ekran goruntusu test sonucu degildir. Sonuclar USB Seri Monitor'dedir.

## Baglantilar

| RC522 | ESP32 GPIO / pin |
| --- | --- |
| SDA / SS | 5 |
| SCK | 18 |
| MOSI | 23 |
| MISO | 19 |
| RST | 27 |
| 3.3V | 3V3 |
| GND | GND |
| IRQ | Baglanmaz |

RC522'ye 5V verme. Lehim, kablo degisikligi ve sureklilik olcumunu enerji kesikken yap.

## Sonuclar

- `0x91` veya `0x92`: Beklenen cip surumu okunuyor. Antenin/kart okumanin calistigini tek basina kanitlamaz.
- `0x00` veya `0xFF`: Haberlesme basarisiz. Besleme, kablo, lehim veya modul arizasi olabilir; kesin bozuk demek degildir.
- Diger surumler: Klon cip veya kararsiz haberlesme olabilir. Tek basina saglamlik ya da ariza sonucu cikarma.
- `BASARILI - KART UID: ...`: Kart gercekten okundu; okuyucu bu kartla calisiyor.
- Her 5 saniyede durum yazilip kart okunmuyorsa: Daha once calisan kartla, kisa kablolarla ve metal yuzeylerden uzakta dene. Besleme ve lehimleri kontrol et.

RC522 icin uyumlu 13.56 MHz ISO/IEC 14443A kart gerekir; 125 kHz kartlar bu okuyucuyla okunmaz.

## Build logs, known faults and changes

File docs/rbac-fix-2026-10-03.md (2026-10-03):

# Kullanıcı, rol ve modül erişimi düzeltmesi — 3 Ekim 2026

Canlıya uygulanan derleme: `UIy8FYLZxassOqjJUloEN`.

## Neden

Canlı servis kayıtlarında kullanıcı doğrulaması ve kendi rolünü değiştirme yasağı gibi beklenen hataların doğrudan fırlatıldığı görüldü. Next.js üretim ortamında bu mesajları gizleyerek genel hata ekranını gösteriyordu. Modül kapatılırken rol/modül kayıtlarının silinmesi de lisans yeniden açıldığında erişimin geri gelmesini engelliyordu.

## Davranış

- Kullanıcı, üyelik, rol ve ekip formları beklenen hataları Türkçe işlem sonucu olarak gösterir; form verilerini korur. Next.js yönlendirmeleri hata olarak yutulmaz.
- Bilinmeyen hatalarda özel sunucu ayrıntıları gösterilmez; günlükle eşleşen hata kodu verilir. Sayfa ve kök yerleşim hataları için Türkçe hata ekranları vardır.
- Firma sahibinin platform lisansları bütün firma üyelerinin erişiminin üst sınırıdır. Eski firmalarda firma sahibi üyeliği bulunmuyorsa mevcut birincil ADMIN kullanılır.
- Lisans kapatma rol tanımlarını silmez. Açık oturumlarda her yeni istekte lisans tekrar kontrol edilir; yeniden açma tanımlı rol erişimini geri getirir.
- Son lisans veya son rol modülü kaldırılabilir. Kullanıcı genel sunucu hatası yerine açık modül bulunmadığı açıklamasını görür.
- Kapalı modüller rol editöründe gösterilmez; açık modüllere yapılan değişiklikler kapalı modüllerin kayıtlı izinlerini silmez.
- Eski birincil firma yöneticisinin mevcut İK erişimi lisans tablosuna bir defalık aktarıldı. Yeni modül erişimi açılmadı. İşlem `LICENSE_LEGACY_BACKFILL` olarak kaydedildi.

## Doğrulama

- 51 birim testi, TypeScript kontrolü, değişen işlem kodlarında ESLint ve üretim derlemesi geçti.
- Ayrı doğrulama servisinde staging veritabanındaki geçici hesaplarla gerçek tarayıcı testleri yapıldı: süper admin kullanıcı oluşturma, mükerrer kayıt mesajı ve form koruma, firma kullanıcısı oluşturma, rol oluşturma/değiştirme, üyelik askıya alma/etkinleştirme, lisans kapatma/yeniden açma, son modülü kaldırma, açık oturumlarda erişim kesilmesi, kapalı modül izinlerinin korunması ve eski ADMIN uyumluluğu.
- Son paket 1440px ve 390px genişliklerde incelendi; yatay taşma, başlık/geri düğmesi çakışması ve birincil buton görünürlüğü kontrol edildi.
- Canlı kullanıcı/rol sayfaları kimlik doğrulanmış isteklerle kontrol edildi. Gerçek HTTPS adresinde geçersiz kullanıcı adı gönderimi Türkçe form hatası döndürdü; kayıt oluşturulmadı ve form değerleri korundu.
- 14 geçici test hesabı ve 2 geçici firma staging ortamından kaldırıldı; doğrulama servisi durduruldu.

## Yayın ve geri dönüş

Canlı uygulama dizini: `/var/www/rfid-personel-takip`.

Yayın öncesi kaynak, derleme ve veritabanı yedeği: `/var/backups/rfid-rbac-20261003`. Yayın betiği aynı dizindeki `deploy.sh` dosyasında tutulur. Eski derleme `build-before`, kaynaklar `source-before.tar` içindedir. Uygulama geri dönüşünde bu iki kaynak birlikte kullanılmalıdır. Sonradan oluşan hareket verilerini kaybetmemek için uygulama geri dönüşü amacıyla bütün veritabanı yedeği geri yüklenmemelidir.

Yerel ve canlı kaynak değişiklikleri Git çalışma ağacındadır; sonraki Git dağıtımından önce bu düzeltmeler sürüm kontrolüne alınmalıdır. Kullanıcıların yayın öncesinden açık kalan sekmelerini bir kez tam yenilemesi gerekir.

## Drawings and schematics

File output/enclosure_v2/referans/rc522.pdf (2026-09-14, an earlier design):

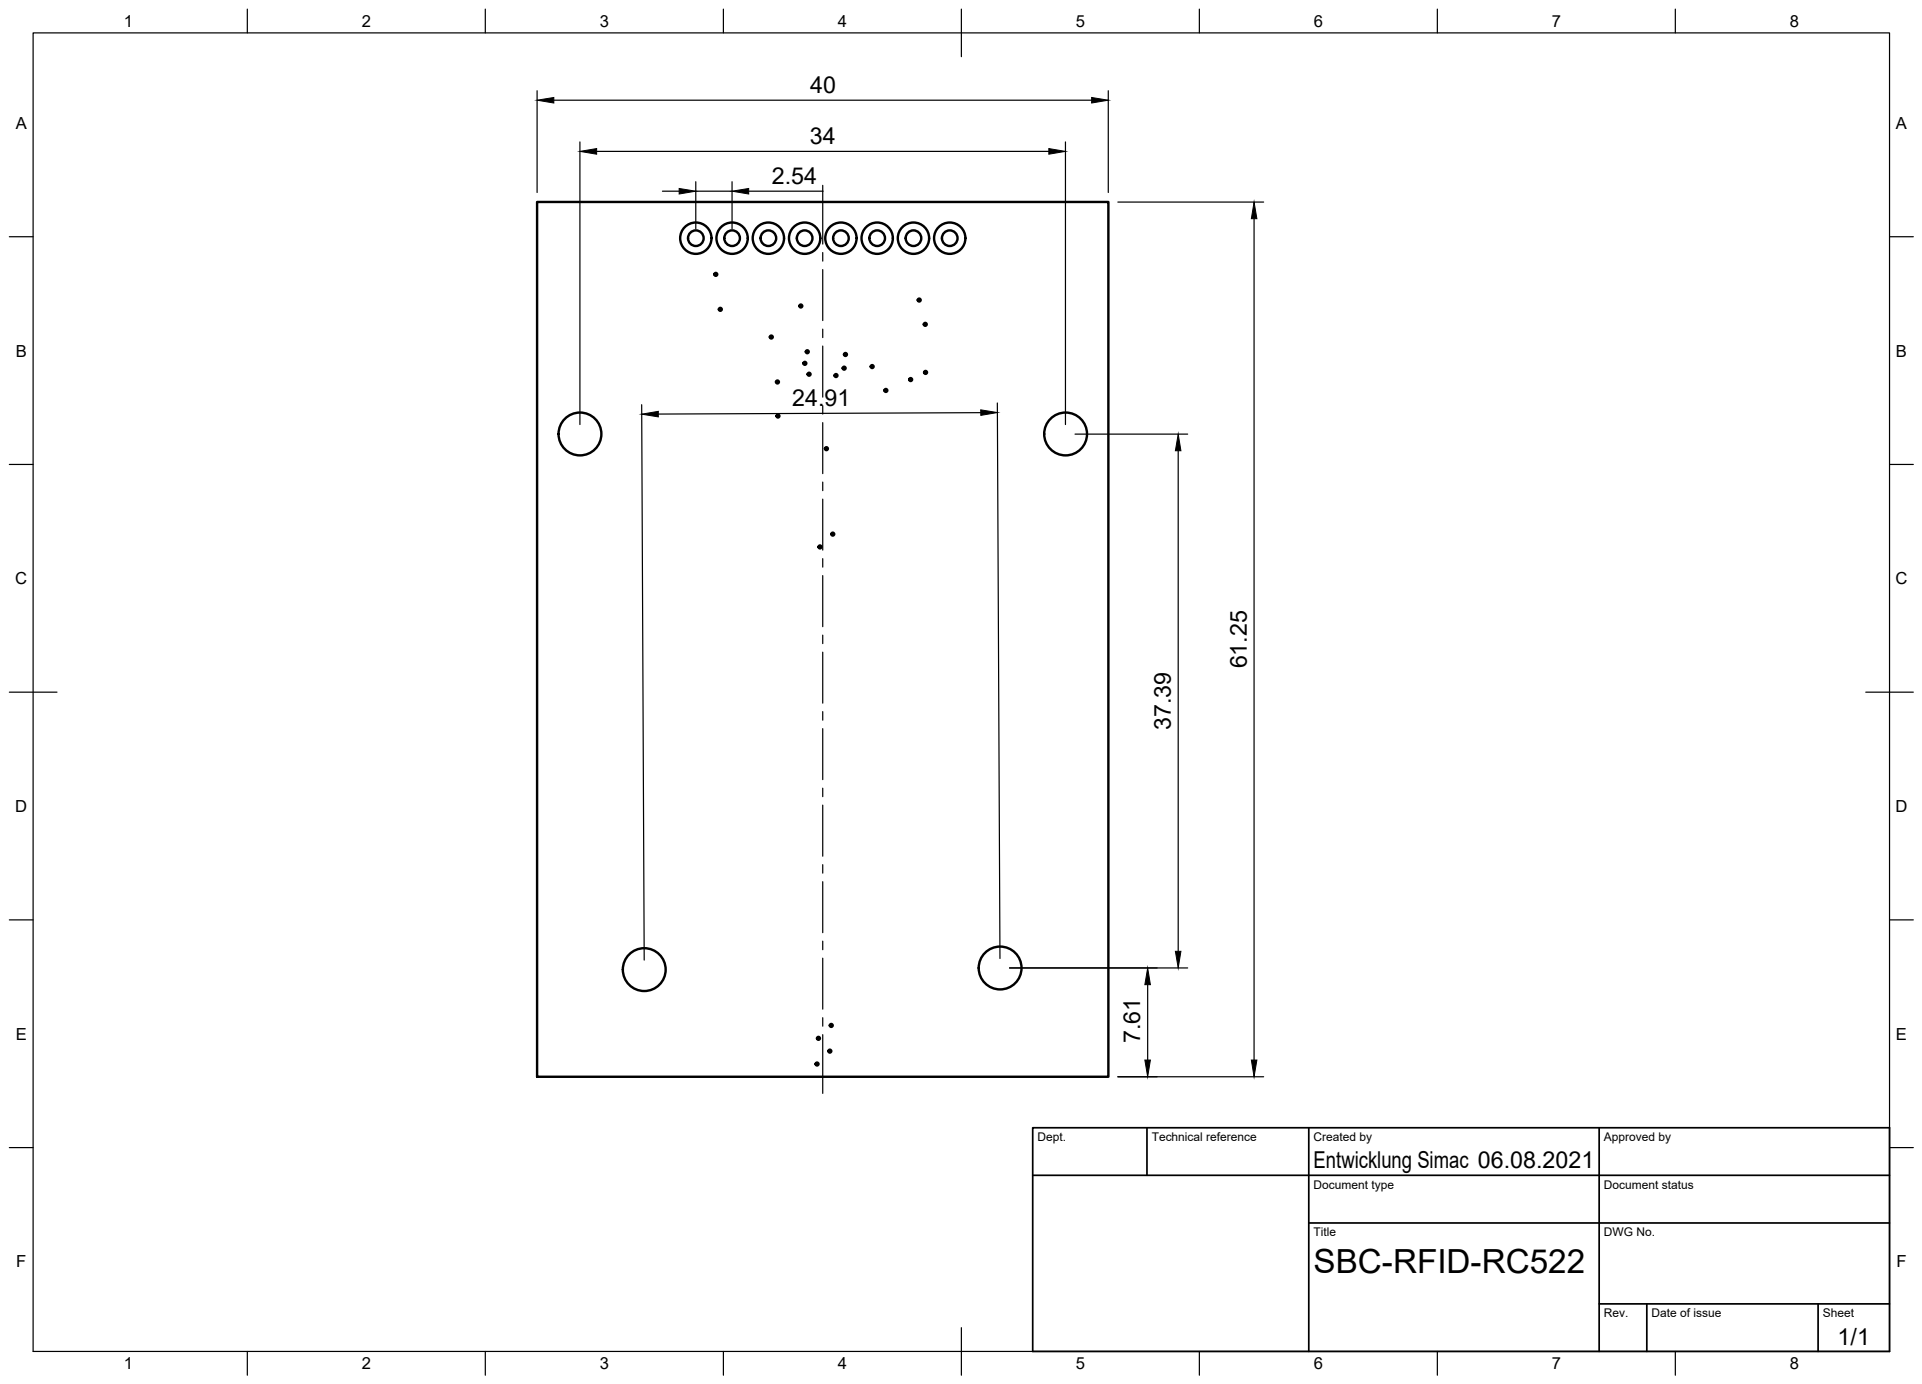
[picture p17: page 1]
Title; DWG No.; Rev.; Date of issue; Sheet

Dept. | Technical reference | Created by Entwicklung Simac 06.08.2021 | Approved by

Document type | Document status

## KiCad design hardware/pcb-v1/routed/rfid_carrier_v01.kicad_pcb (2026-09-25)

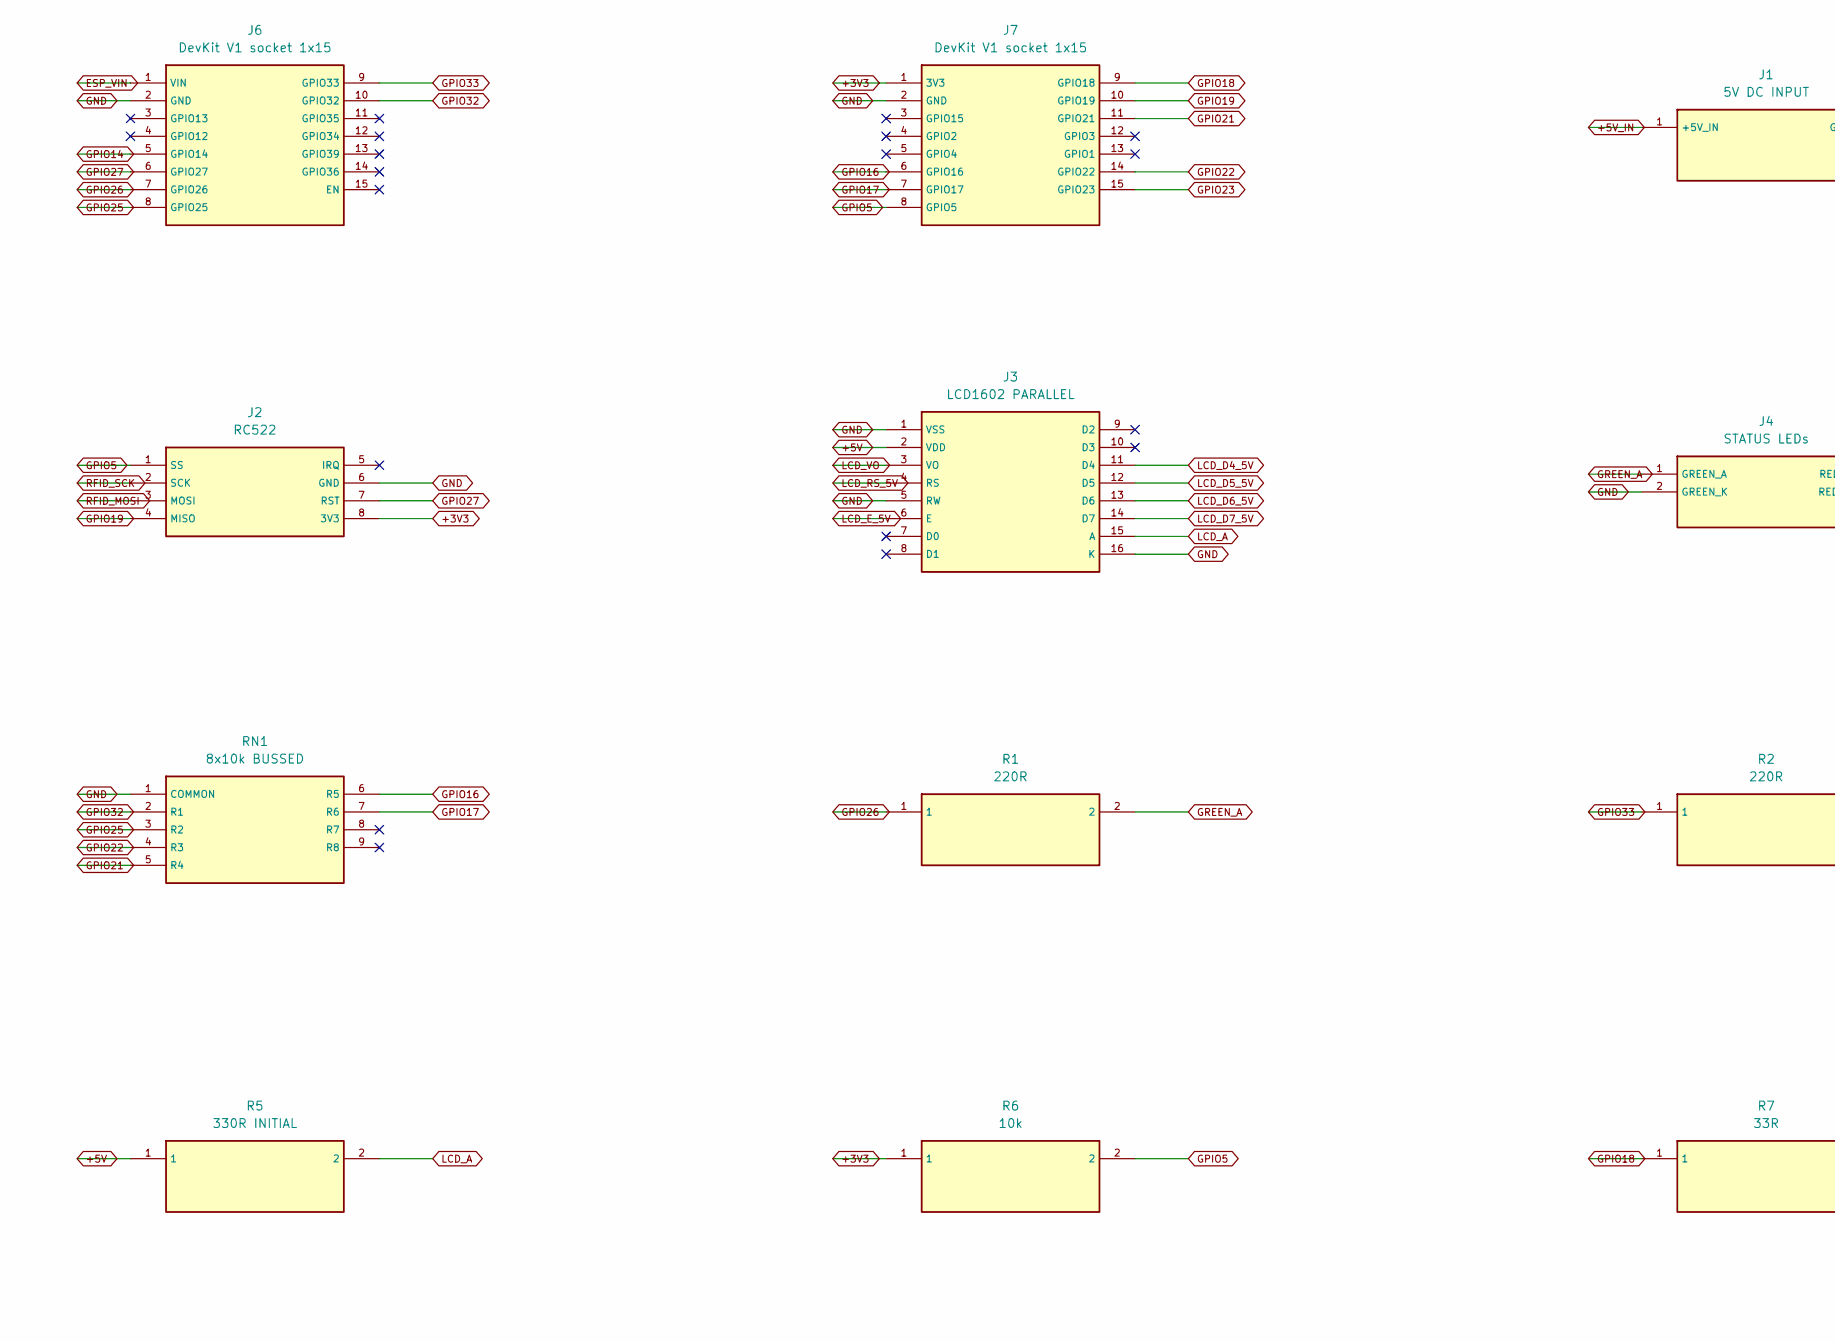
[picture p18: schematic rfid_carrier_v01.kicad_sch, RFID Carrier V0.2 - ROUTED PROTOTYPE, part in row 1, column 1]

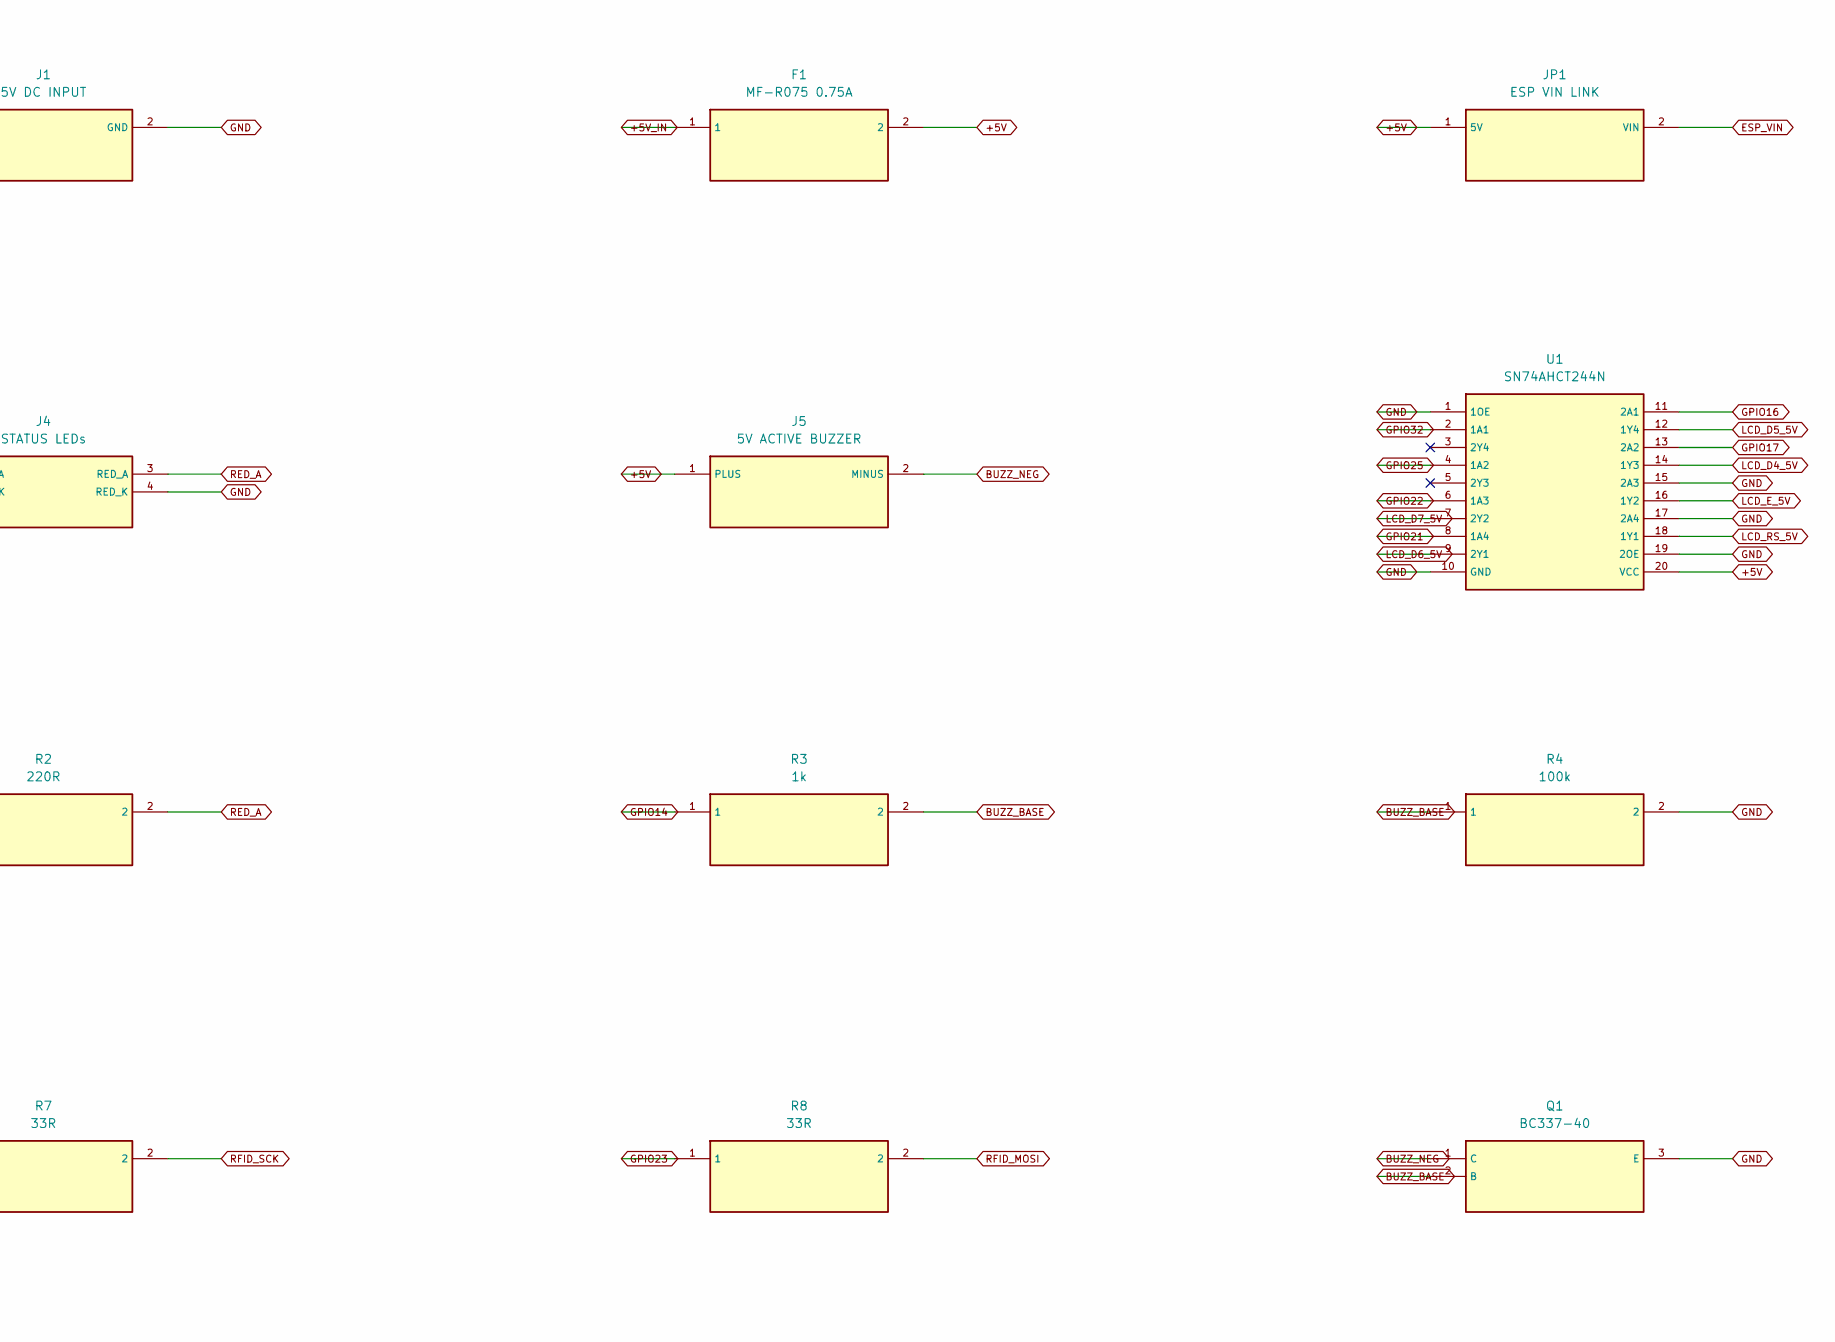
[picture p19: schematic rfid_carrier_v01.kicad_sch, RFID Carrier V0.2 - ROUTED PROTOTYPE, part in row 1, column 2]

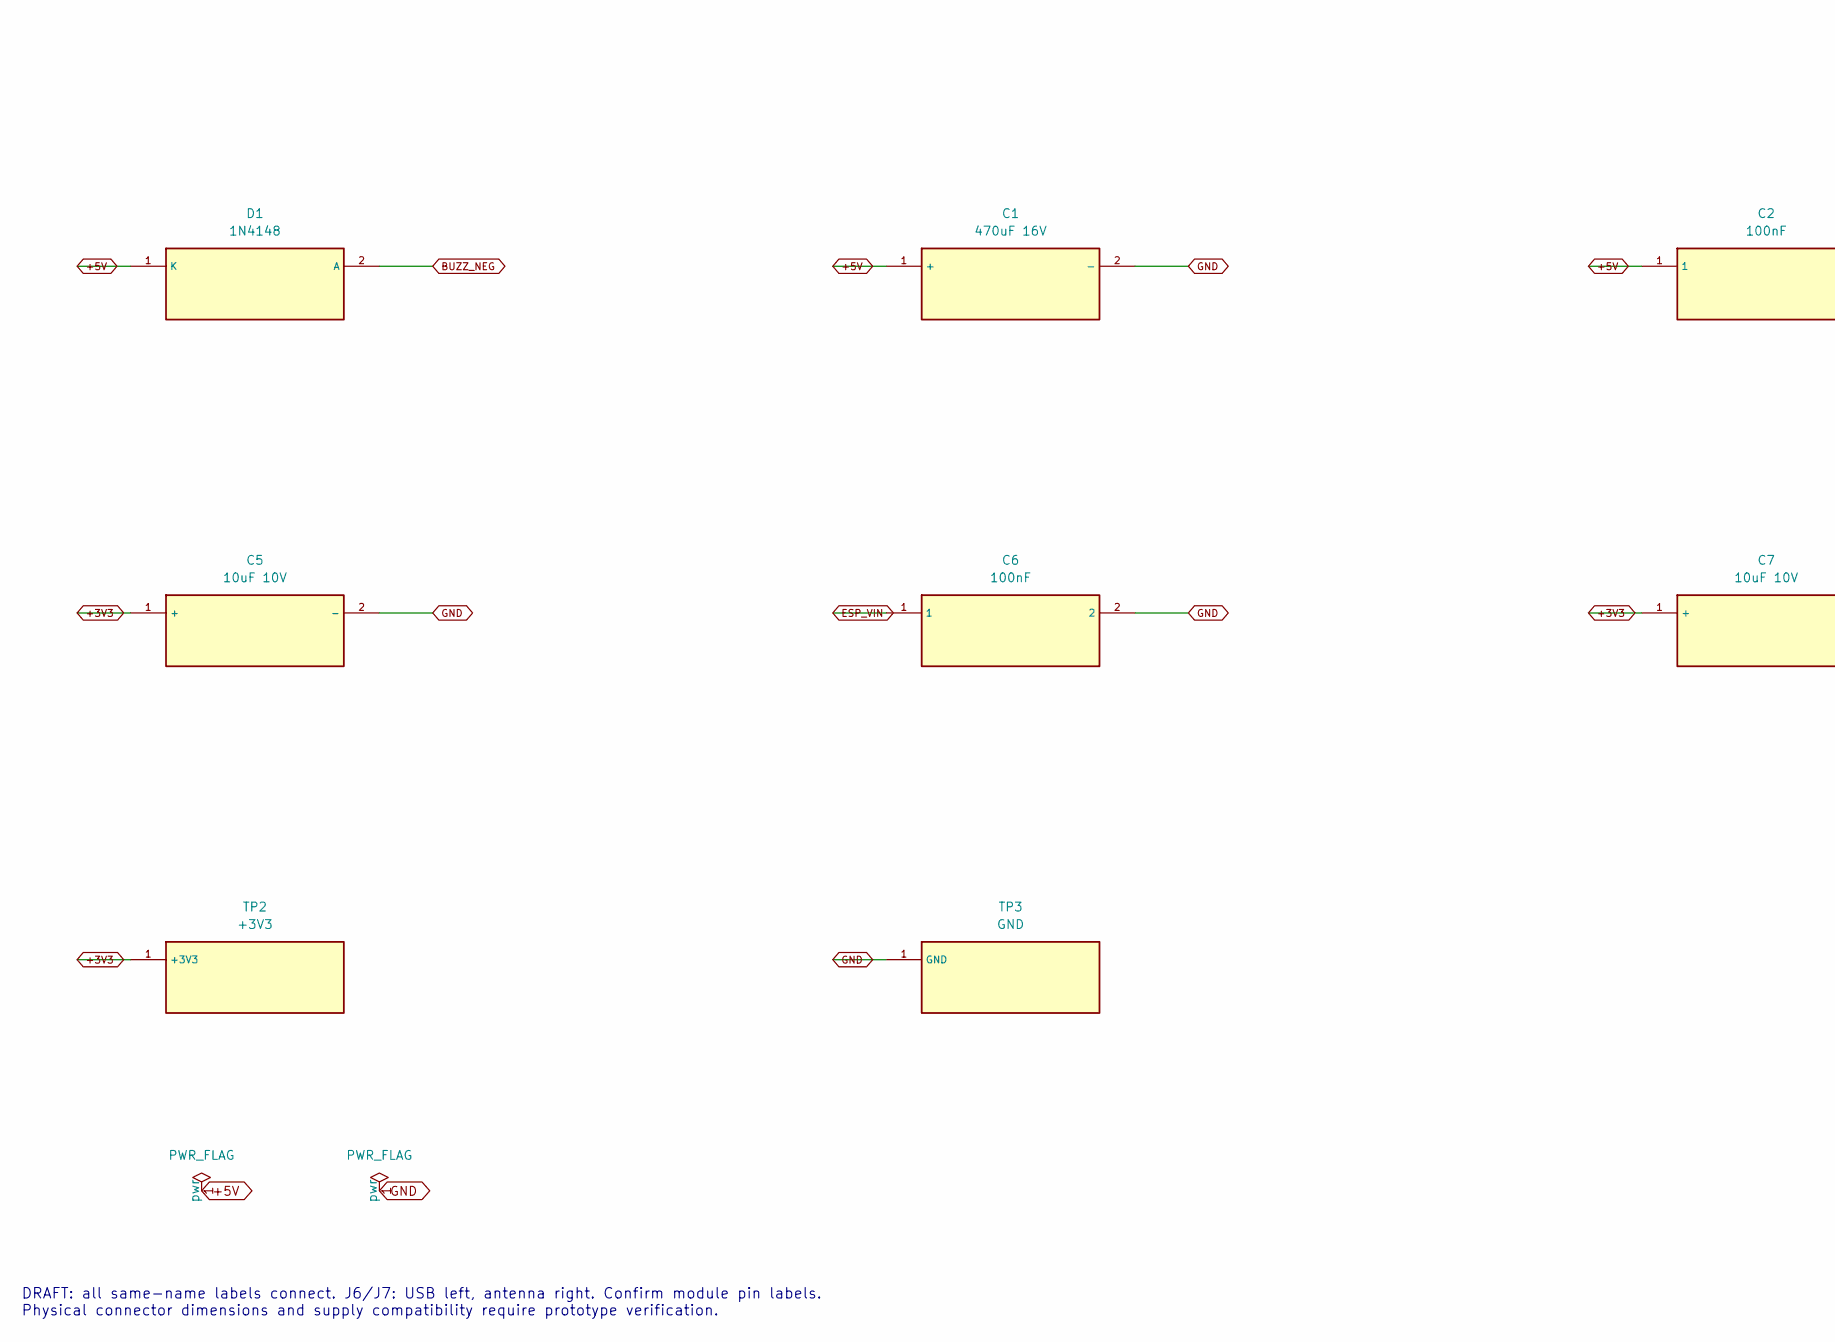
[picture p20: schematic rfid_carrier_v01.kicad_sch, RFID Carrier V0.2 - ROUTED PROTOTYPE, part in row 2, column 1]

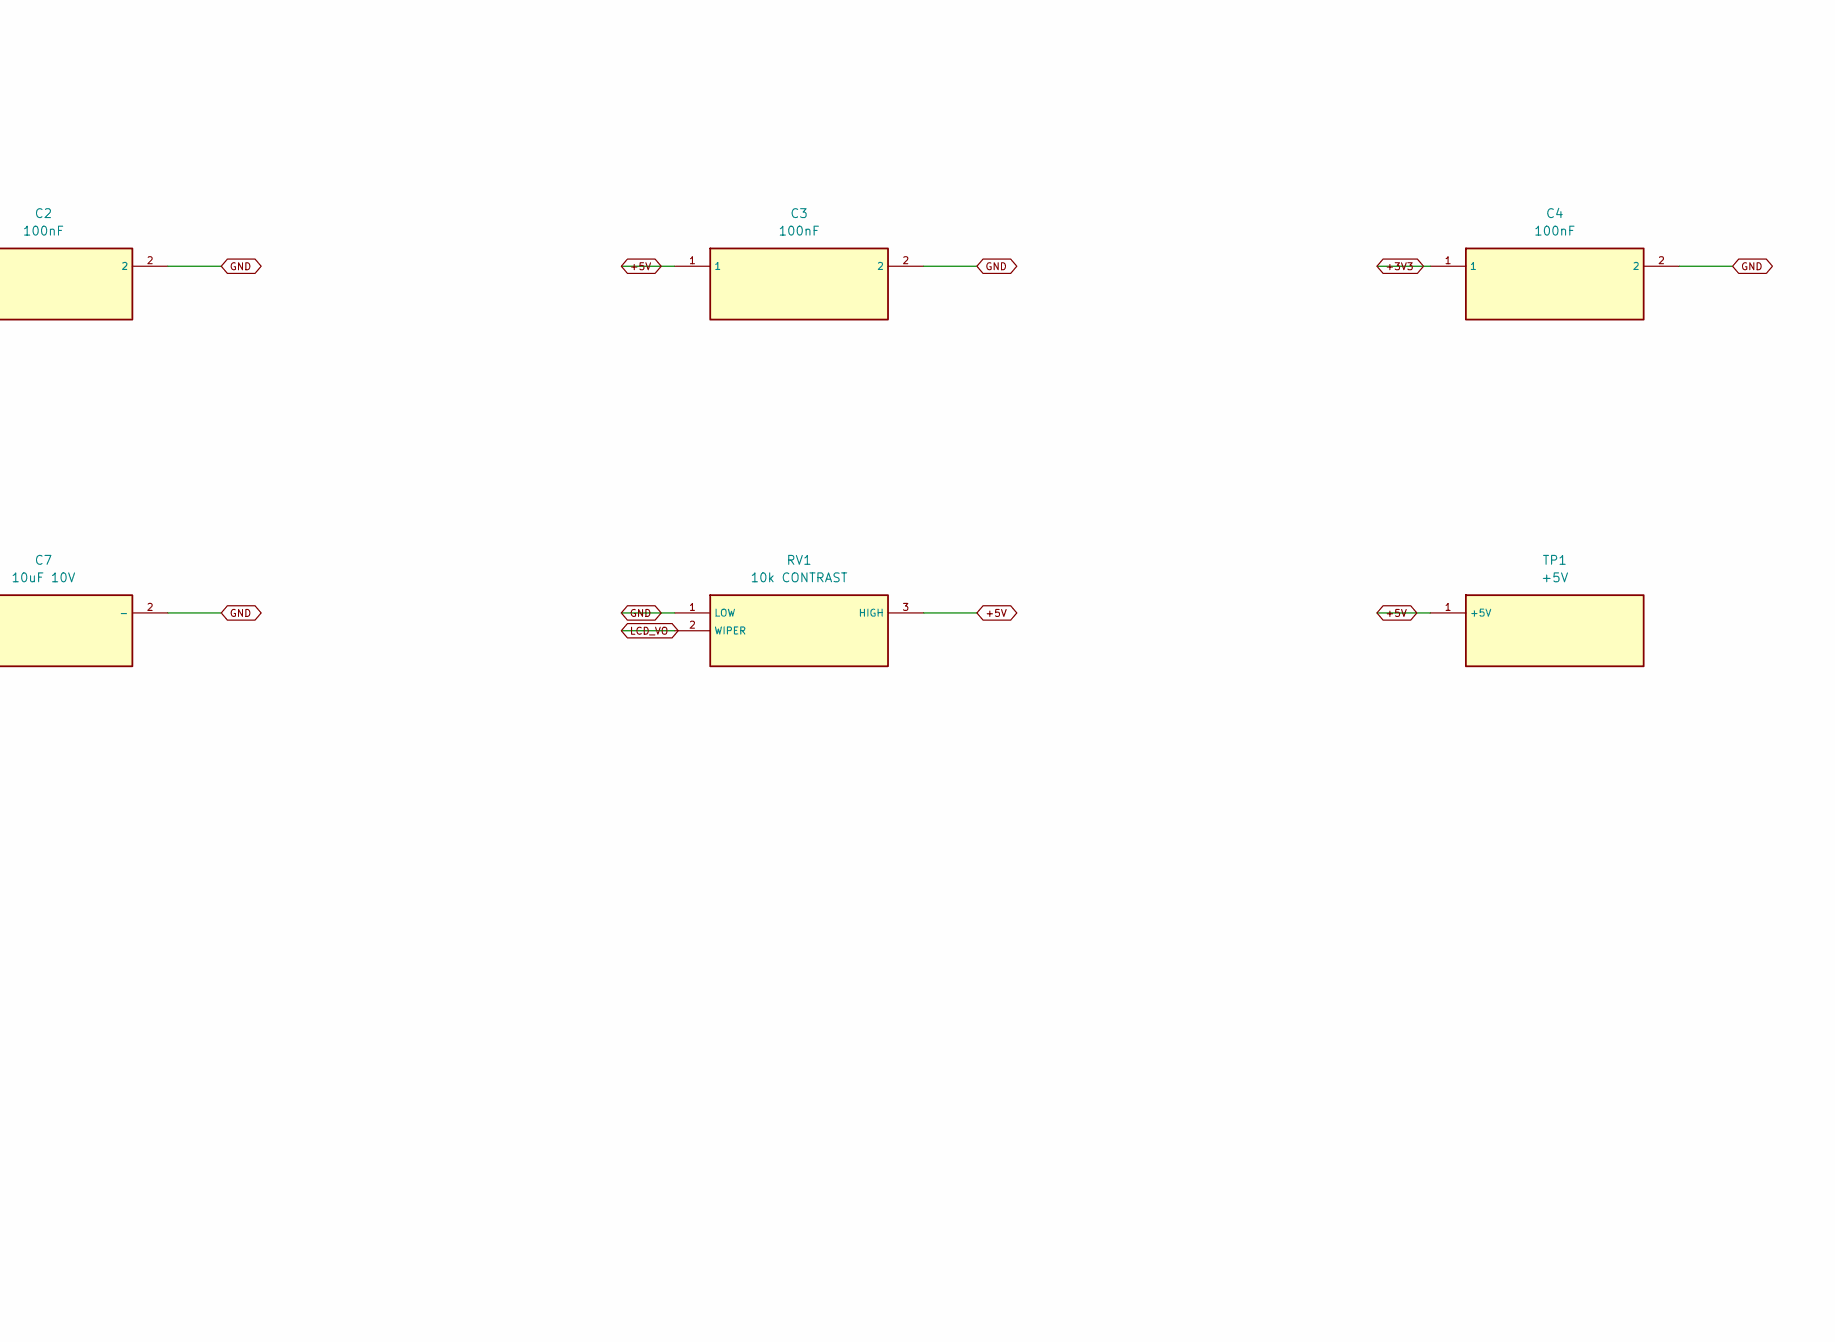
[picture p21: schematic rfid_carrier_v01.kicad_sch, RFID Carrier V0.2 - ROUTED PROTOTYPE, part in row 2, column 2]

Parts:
C1: 470uF 16V; C1_CP_P3.5_H
C2: 100nF; C2_C_P2.54_H
C3: 100nF; C3_C_P2.54_H
C4: 100nF; C4_C_P2.54_H
C5: 10uF 10V; C5_CP_P2_H
C6: 100nF; C6_C_P2.54_H
C7: 10uF 10V; C7_CP_P2_H
D1: 1N4148; D1_D_P7.62_H
F1: MF-R075 0.75A; F1_PTC_P5.08_H
J1: 5V DC INPUT; J1_Header_2_P5.08_V
J2: RC522; J2_Header_8_P2.54_H
J3: LCD1602 PARALLEL; J3_Header_16_P2.54_H
J4: STATUS LEDs; J4_Header_4_P2.54_H
J5: 5V ACTIVE BUZZER; J5_Header_2_P2.54_H
J6: DevKit V1 socket 1x15; J6_Header_15_P2.54_H
J7: DevKit V1 socket 1x15; J7_Header_15_P2.54_H
JP1: ESP VIN LINK; JP1_Header_2_P2.54_V
Q1: BC337-40; Q1_TO92_CBE_FORMED_P2.54
R1: 220R; R1_R_P7.62_V
R2: 220R; R2_R_P7.62_V
R3: 1k; R3_R_P7.62_H
R4: 100k; R4_R_P7.62_H
R5: 330R INITIAL; R5_R_P7.62_H
R6: 10k; R6_R_P7.62_H
R7: 33R; R7_R_P7.62_V
R8: 33R; R8_R_P7.62_V
RN1: 8x10k BUSSED; RN1_Header_9_P2.54_V
RV1: 10k CONTRAST; RV1_Trimmer_3pin_5.08x2.54
TP1: +5V; TP1_TestPoint_THT
TP2: +3V3; TP2_TestPoint_THT
TP3: GND; TP3_TestPoint_THT
U1: SN74AHCT244N; U1_DIP20_W7.62

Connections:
+3V3: C4.1, C5.1 (+), C7.1 (+), J2.8 (3V3), J7.1 (3V3), R6.1, TP2.1
+5V: C1.1 (+), C2.1, C3.1, D1.1 (K), F1.2, J3.2 (VDD), J5.1 (PLUS), JP1.1 (5V), R5.1, RV1.3 (HIGH), TP1.1, U1.20 (VCC)
+5V_IN: F1.1, J1.1 (+5V_IN)
BUZZ_BASE: Q1.2 (B), R3.2, R4.1
BUZZ_NEG: D1.2 (A), J5.2 (MINUS), Q1.1 (C)
ESP_VIN: C6.1, J6.1 (VIN), JP1.2 (VIN)
GND: C1.2 (-), C2.2, C3.2, C4.2, C5.2 (-), C6.2, C7.2 (-), J1.2 (GND), J2.6 (GND), J3.1 (VSS), J3.5 (RW), J3.16 (K), J4.2 (GREEN_K), J4.4 (RED_K), J6.2 (GND), J7.2 (GND), Q1.3 (E), R4.2, RN1.1 (COMMON), RV1.1 (LOW), TP3.1, U1.1 (1OE), U1.10 (GND), U1.15 (2A3), U1.17 (2A4), U1.19 (2OE)
GPIO5: J2.1 (SS), J7.8 (GPIO5), R6.2
GPIO14: J6.5 (GPIO14), R3.1
GPIO16: J7.6 (GPIO16), RN1.6 (R5), U1.11 (2A1)
GPIO17: J7.7 (GPIO17), RN1.7 (R6), U1.13 (2A2)
GPIO18: J7.9 (GPIO18), R7.1
GPIO19: J2.4 (MISO), J7.10 (GPIO19)
GPIO21: J7.11 (GPIO21), RN1.5 (R4), U1.8 (1A4)
GPIO22: J7.14 (GPIO22), RN1.4 (R3), U1.6 (1A3)
GPIO23: J7.15 (GPIO23), R8.1
GPIO25: J6.8 (GPIO25), RN1.3 (R2), U1.4 (1A2)
GPIO26: J6.7 (GPIO26), R1.1
GPIO27: J2.7 (RST), J6.6 (GPIO27)
GPIO32: J6.10 (GPIO32), RN1.2 (R1), U1.2 (1A1)
GPIO33: J6.9 (GPIO33), R2.1
GREEN_A: J4.1 (GREEN_A), R1.2
LCD_A: J3.15 (A), R5.2
LCD_D4_5V: J3.11 (D4), U1.14 (1Y3)
LCD_D5_5V: J3.12 (D5), U1.12 (1Y4)
LCD_D6_5V: J3.13 (D6), U1.9 (2Y1)
LCD_D7_5V: J3.14 (D7), U1.7 (2Y2)
LCD_E_5V: J3.6 (E), U1.16 (1Y2)
LCD_RS_5V: J3.4 (RS), U1.18 (1Y1)
LCD_VO: J3.3 (VO), RV1.2 (WIPER)
RED_A: J4.3 (RED_A), R2.2
RFID_MOSI: J2.3 (MOSI), R8.2
RFID_SCK: J2.2 (SCK), R7.2

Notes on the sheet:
DRAFT: all same-name labels connect. J6/J7: USB left, antenna right. Confirm module pin labels. Physical connector dimensions and supply compatibility require prototype verification.

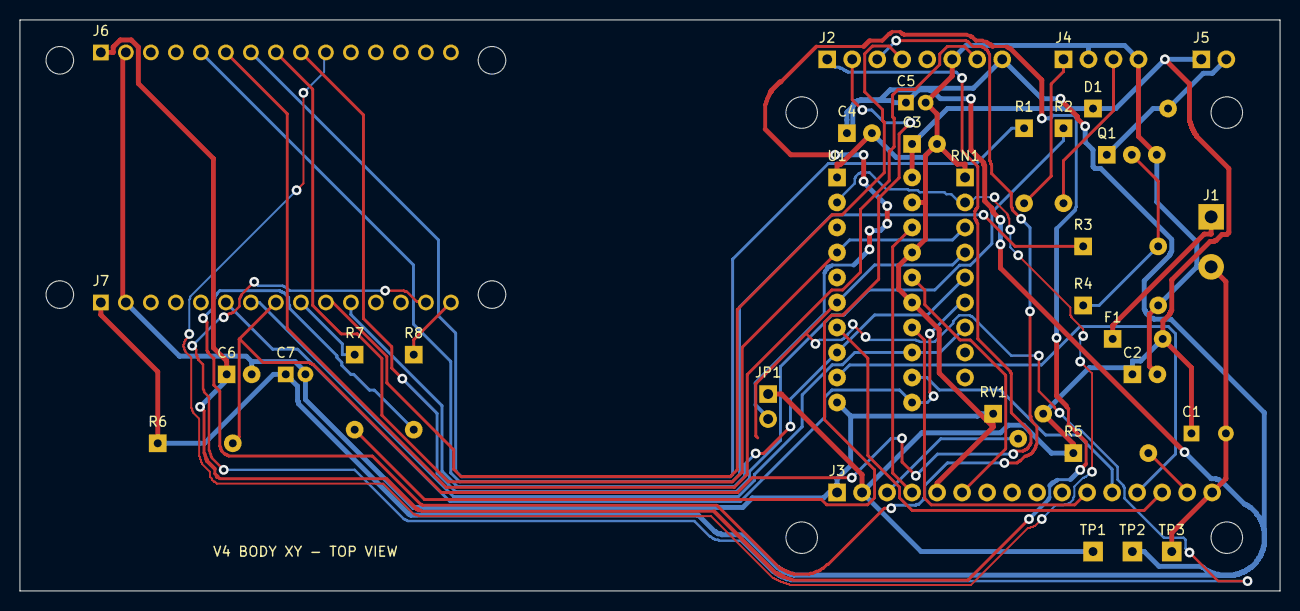
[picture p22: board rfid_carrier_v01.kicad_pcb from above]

Board: 2 copper layers, 128.0 x 58.0 mm, 40 parts (0 on the bottom side), 33 nets.

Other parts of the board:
H1, H2, H3, H4: MountingHole_2.8mm
H5, H6, H7, H8: MountingHole_3.2mm

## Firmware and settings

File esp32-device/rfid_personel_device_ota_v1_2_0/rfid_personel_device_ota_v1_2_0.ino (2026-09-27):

#include <WiFi.h>
#include <WebServer.h>
#include <DNSServer.h>
#include <Preferences.h>
#include <HTTPClient.h>
#include <WiFiClientSecure.h>
#include <ArduinoJson.h>
#include <SPI.h>
#include <MFRC522.h>
#include <LiquidCrystal.h>
#include <LittleFS.h>
#include <Update.h>
#include <SHA2Builder.h>
#include <time.h>
#include "ota_root_ca.h"

// ESP32 pinleri. Kendi baglantina gore burayi degistirebilirsin.
#define RFID_SS_PIN 5
#define RFID_RST_PIN 27
#define GREEN_LED_PIN 26
#define RED_LED_PIN 33
#define BUZZER_PIN 14

// Donusturucusuz 2x16 paralel LCD (4-bit mod)
#define LCD_RS_PIN 32
#define LCD_ENABLE_PIN 25
#define LCD_D4_PIN 22
#define LCD_D5_PIN 21
#define LCD_D6_PIN 16
#define LCD_D7_PIN 17

#define LCD_COLUMNS 16
#define LCD_ROWS 2

#ifndef RFID_FIRMWARE_VERSION
#define RFID_FIRMWARE_VERSION "1.2.0"
#endif
#ifndef RFID_DEFAULT_API_BASE_URL
#define RFID_DEFAULT_API_BASE_URL "https://flodeska.com"
#endif
#ifndef RFID_FORCE_DEFAULT_API_BASE_URL
#define RFID_FORCE_DEFAULT_API_BASE_URL false
#endif

const char* FIRMWARE_VERSION = RFID_FIRMWARE_VERSION;
const char* DEFAULT_API_BASE_URL = RFID_DEFAULT_API_BASE_URL;
const char* DEFAULT_DEVICE_SECRET_KEY = "";
const bool FORCE_DEFAULT_API_BASE_URL = RFID_FORCE_DEFAULT_API_BASE_URL;

const unsigned long WIFI_RETRY_MS = 5000;
const unsigned long WIFI_CONNECT_TIMEOUT_MS = 15000;
const unsigned long CONFIG_PORTAL_WIFI_RETRY_MS = 5UL * 60UL * 1000UL;
const unsigned long HEARTBEAT_INTERVAL_MS = 30000;
const unsigned long RFID_DEBOUNCE_MS = 2500;
const unsigned long QUEUE_FLUSH_INTERVAL_MS = 10000;
const size_t OFFLINE_QUEUE_MAX_PENDING_BYTES = 64UL * 1024UL;
const int MAX_QUEUE_SEND_PER_LOOP = 5;
const char* OFFLINE_QUEUE_PATH = "/rfid_queue.ndjson";
const unsigned long OTA_CHECK_INTERVAL_MS = 6UL * 60UL * 60UL * 1000UL;
const unsigned long OTA_RETRY_INTERVAL_MS = 5UL * 60UL * 1000UL;
const unsigned long OTA_INITIAL_CHECK_DELAY_MS = 30UL * 1000UL;
const byte DNS_PORT = 53;

MFRC522 rfid(RFID_SS_PIN, RFID_RST_PIN);
LiquidCrystal lcd(
  LCD_RS_PIN,
  LCD_ENABLE_PIN,
  LCD_D4_PIN,
  LCD_D5_PIN,
  LCD_D6_PIN,
  LCD_D7_PIN
);
Preferences preferences;
WebServer configServer(80);
DNSServer dnsServer;

String savedWifiSsid = "";
String savedWifiPassword = "";
String apiBaseUrl = "";
String deviceSecretKey = "";
String setupApSsid = "";
String lastCardId = "";
String lastSendError = "";

bool isConfigPortalActive = false;
bool configPortalRoutesRegistered = false;
unsigned long lastWifiAttemptAt = 0;
unsigned long lastConfigPortalWifiAttemptAt = 0;
unsigned long lastHeartbeatAt = 0;
unsigned long lastCardReadAt = 0;
unsigned long lastQueueFlushAt = 0;
unsigned long nextFirmwareCheckAt = OTA_INITIAL_CHECK_DELAY_MS;
int lastDisplayedSecond = -1;
bool idleClockActive = false;
bool otaInProgress = false;
bool bootOtaResultReported = false;
bool queueStorageReady = false;

String htmlEscape(const String& value) {
  String escaped = value;
  escaped.replace("&", "&amp;");
  escaped.replace("<", "&lt;");
  escaped.replace(">", "&gt;");
  escaped.replace("\"", "&quot;");
  return escaped;
}

String fitLcdText(const String& text) {
  if (text.length() <= LCD_COLUMNS) {
    return text;
  }
  return text.substring(0, LCD_COLUMNS);
}

void showLcd(const String& line1, const String& line2 = "") {
  idleClockActive = false;
  lcd.clear();
  lcd.setCursor(0, 0);
  lcd.print(fitLcdText(line1));
  lcd.setCursor(0, 1);
  lcd.print(fitLcdText(line2));
}

void showIdleClock(bool forceRefresh = false) {
  struct tm timeInfo;
  if (!getLocalTime(&timeInfo, 20)) {
    if (forceRefresh || !idleClockActive) {
      showLcd("Kart bekleniyor", "Saat bekleniyor");
      idleClockActive = true;
    }
    return;
  }

  if (!forceRefresh && idleClockActive && timeInfo.tm_sec == lastDisplayedSecond) {
    return;
  }

  char timeText[9];
  strftime(timeText, sizeof(timeText), "%H:%M:%S", &timeInfo);
  if (forceRefresh || !idleClockActive) {
    showLcd("Kart bekleniyor", String(timeText));
  } else {
    lcd.setCursor(0, 1);
    lcd.print("                ");
    lcd.setCursor(0, 1);
    lcd.print(timeText);
  }
  idleClockActive = true;
  lastDisplayedSecond = timeInfo.tm_sec;
}

void setStatusLed(bool green, bool red) {
  digitalWrite(GREEN_LED_PIN, green ? HIGH : LOW);
  digitalWrite(RED_LED_PIN, red ? HIGH : LOW);
}

void beep(unsigned int durationMs = 110) {
  digitalWrite(BUZZER_PIN, HIGH);
  delay(durationMs);
  digitalWrite(BUZZER_PIN, LOW);
}

void successSignal() {
  setStatusLed(true, false);
  beep(65);
  delay(65);
  beep(65);
  setStatusLed(false, false);
}

void errorSignal() {
  setStatusLed(false, true);
  beep(260);
  delay(180);
  beep(260);
  setStatusLed(false, false);
}

void unknownCardSignal() {
  setStatusLed(false, true);
  beep(650);
  delay(180);
  beep(100);
  delay(90);
  beep(100);
  delay(90);
  beep(100);
  setStatusLed(false, false);
}

String getApSsid() {
  uint64_t chipId = ESP.getEfuseMac();
  char suffix[7];
  snprintf(suffix, sizeof(suffix), "%06X", (uint32_t)(chipId & 0xFFFFFF));
  return "RFIDPersonel-" + String(suffix);
}

String getMacAddress() {
  return WiFi.macAddress();
}

void loadConfig() {
  preferences.begin("rfidpdks", true);
  savedWifiSsid = preferences.getString("wifi_ssid", "");
  savedWifiPassword = preferences.getString("wifi_pass", "");
  apiBaseUrl = preferences.getString("api_url", DEFAULT_API_BASE_URL);
  deviceSecretKey = preferences.getString("secret_key", DEFAULT_DEVICE_SECRET_KEY);
  preferences.end();

  apiBaseUrl.trim();
  deviceSecretKey.trim();
}

void saveConfig(const String& ssid, const String& password, const String& apiUrl, const String& secretKey) {
  preferences.begin("rfidpdks", false);
  preferences.putString("wifi_ssid", ssid);
  preferences.putString("wifi_pass", password);
  preferences.putString("api_url", apiUrl);
  preferences.putString("secret_key", secretKey);
  preferences.end();

  savedWifiSsid = ssid;
  savedWifiPassword = password;
  apiBaseUrl = apiUrl;
  deviceSecretKey = secretKey;
}

bool isHttpsUrl(const String& url) {
  return url.startsWith("https://");
}

String normalizeApiBaseUrl(String url) {
  url.trim();
  while (url.endsWith("/")) {
    url.remove(url.length() - 1);
  }
  return url;
}

bool beginHttp(HTTPClient& http, WiFiClient& client, WiFiClientSecure& secureClient, const String& endpoint) {
  if (isHttpsUrl(endpoint)) {
    secureClient.setCACert(OTA_ROOT_CA);
    return http.begin(secureClient, endpoint);
  }

  return http.begin(client, endpoint);
}

String buildWifiOptionsHtml() {
  int networkCount = WiFi.scanNetworks();
  String options = "";

  if (networkCount <= 0) {
    return "<option value=\"\">Ag bulunamadi</option>";
  }

  for (int i = 0; i < networkCount; i++) {
    String ssid = WiFi.SSID(i);
    if (ssid.length() == 0) {
      continue;
    }

    options += "<option value=\"" + htmlEscape(ssid) + "\">";
    options += htmlEscape(ssid) + " (" + String(WiFi.RSSI(i)) + " dBm)";
    options += "</option>";
  }

  WiFi.scanDelete();
  return options;
}

void handleConfigRoot() {
  String html = "<!doctype html><html lang=\"tr\"><head><meta charset=\"utf-8\">";
  html += "<meta name=\"viewport\" content=\"width=device-width,initial-scale=1\">";
  html += "<title>RFID Personel Kurulum</title>";
  html += "<style>body{margin:0;font-family:Arial,sans-serif;background:#eef6fb;color:#0f172a}";
  html += ".wrap{max-width:540px;margin:0 auto;padding:24px}.card{background:#fff;border:1px solid #dbe3ef;border-radius:10px;padding:22px}";
  html += "h1{font-size:24px;margin:0 0 8px}p{color:#475569;line-height:1.5}label{display:block;margin-top:14px;font-weight:700}";
  html += "select,input,button{width:100%;box-sizing:border-box;margin-top:6px;padding:12px;border-radius:6px;border:1px solid #cbd5e1;font-size:16px}";
  html += "button{background:#0284c7;color:#fff;border:0;font-weight:700;margin-top:18px}.hint{font-size:13px;color:#64748b}</style></head><body>";
  html += "<main class=\"wrap\"><section class=\"card\"><h1>RFID Personel Kurulum</h1>";
  html += "<p>Wi-Fi agini sec, API adresini ve cihaz secret key bilgisini gir. Kayit sonrasi cihaz yeniden baslar.</p>";
  html += "<form method=\"post\" action=\"/save\"><label>Wi-Fi Agi</label><select name=\"ssid\" required>";
  html += buildWifiOptionsHtml();
  html += "</select><label>Wi-Fi Sifresi</label><input name=\"password\" type=\"password\" autocomplete=\"current-password\">";
  html += "<label>API Adresi</label><input name=\"apiUrl\" required value=\"" + htmlEscape(apiBaseUrl) + "\">";
  html += "<label>Cihaz Secret Key</label><input name=\"secretKey\" required value=\"" + htmlEscape(deviceSecretKey) + "\">";
  html += "<button type=\"submit\">Kaydet ve Yeniden Baslat</button></form>";
  html += "<p class=\"hint\">Bu ekran acilmazsa tarayicida 192.168.4.1 adresini ac.</p></section></main></body></html>";
  configServer.send(200, "text/html; charset=utf-8", html);
}

void handleConfigSave() {
  String ssid = configServer.arg("ssid");
  String password = configServer.arg("password");
  String apiUrl = normalizeApiBaseUrl(configServer.arg("apiUrl"));
  String secretKey = configServer.arg("secretKey");
  secretKey.trim();

  if (ssid.length() == 0 || apiUrl.length() == 0 || secretKey.length() == 0) {
    configServer.send(400, "text/plain; charset=utf-8", "Wi-Fi, API adresi ve secret key zorunludur.");
    return;
  }

  saveConfig(ssid, password, apiUrl, secretKey);
  showLcd("Ayar kaydedildi", "Yeniden baslar");
  configServer.send(200, "text/html; charset=utf-8", "<html><body><h1>Kaydedildi</h1><p>Cihaz yeniden baslatiliyor.</p></body></html>");
  delay(1500);
  ESP.restart();
}

void handleConfigNotFound() {
  configServer.sendHeader("Location", "/", true);
  configServer.send(302, "text/plain", "");
}

void startConfigPortal() {
  setupApSsid = getApSsid();

  dnsServer.stop();
  configServer.stop();
  WiFi.disconnect(true);
  delay(300);
  WiFi.mode(WIFI_AP_STA);
  WiFi.softAP(setupApSsid.c_str());

  IPAddress apIp = WiFi.softAPIP();
  dnsServer.start(DNS_PORT, "*", apIp);

  if (!configPortalRoutesRegistered) {
    configServer.on("/", HTTP_GET, handleConfigRoot);
    configServer.on("/save", HTTP_POST, handleConfigSave);
    configServer.onNotFound(handleConfigNotFound);
    configPortalRoutesRegistered = true;
  }
  configServer.begin();
  isConfigPortalActive = true;
  lastConfigPortalWifiAttemptAt = millis();

  Serial.print("Kurulum AP: ");
  Serial.println(setupApSsid);
  Serial.print("Kurulum IP: ");
  Serial.println(apIp);
  showLcd(setupApSsid, "192.168.4.1");
}

void stopConfigPortal() {
  dnsServer.stop();
  configServer.stop();
  WiFi.softAPdisconnect(true);
  isConfigPortalActive = false;
}

bool tryConnectWifi(const String& ssid, const String& password) {
  if (ssid.length() == 0) {
    return false;
  }

  Serial.print("Wi-Fi deneniyor: ");
  Serial.println(ssid);
  showLcd("Wi-Fi baglaniyor", ssid);

  WiFi.mode(WIFI_STA);
  WiFi.setSleep(false);
  WiFi.setAutoReconnect(true);
  WiFi.begin(ssid.c_str(), password.c_str());

  unsigned long connectStart = millis();
  while (WiFi.status() != WL_CONNECTED && millis() - connectStart < WIFI_CONNECT_TIMEOUT_MS) {
    delay(300);
  }

  if (WiFi.status() == WL_CONNECTED) {
    Serial.print("Wi-Fi baglandi. IP: ");
    Serial.println(WiFi.localIP());
    showLcd("Wi-Fi baglandi", WiFi.localIP().toString());
    setStatusLed(true, false);
    delay(700);
    setStatusLed(false, false);
    configTime(3 * 3600, 0, "pool.ntp.org", "time.nist.gov");
    return true;
  }

  Serial.println("Wi-Fi baglantisi kurulamadi.");
  WiFi.disconnect(true);
  delay(300);
  return false;
}

void retrySavedWifiFromConfigPortal() {
  if (!isConfigPortalActive || savedWifiSsid.length() == 0) {
    return;
  }

  unsigned long now = millis();
  if (now - lastConfigPortalWifiAttemptAt < CONFIG_PORTAL_WIFI_RETRY_MS) {
    return;
  }

  lastConfigPortalWifiAttemptAt = now;
  Serial.println("Kurulum modunda kayitli Wi-Fi yeniden deneniyor.");
  stopConfigPortal();

  if (tryConnectWifi(savedWifiSsid, savedWifiPassword)) {
    Serial.println("Kayitli Wi-Fi geri geldi. Normal moda gecildi.");
    lastHeartbeatAt = 0;
    showIdleClock(true);
    return;
  }

  Serial.println("Kayitli Wi-Fi hala kullanilamiyor. Kurulum AP yeniden aciliyor.");
  startConfigPortal();
}

void connectWifiIfNeeded() {
  if (isConfigPortalActive || WiFi.status() == WL_CONNECTED) {
    return;
  }

  unsigned long now = millis();
  if (now - lastWifiAttemptAt < WIFI_RETRY_MS) {
    return;
  }

  lastWifiAttemptAt = now;
  if (!tryConnectWifi(savedWifiSsid, savedWifiPassword)) {
    startConfigPortal();
  }
}

bool postJson(const String& path, const String& payload, String& response, int& statusCode) {
  if (WiFi.status() != WL_CONNECTED || apiBaseUrl.length() == 0) {
    statusCode = -1;
    return false;
  }

  String endpoint = apiBaseUrl + path;
  HTTPClient http;
  WiFiClient client;
  WiFiClientSecure secureClient;

  if (!beginHttp(http, client, secureClient, endpoint)) {
    statusCode = -2;
    return false;
  }

  http.addHeader("Content-Type", "application/json");
  http.addHeader("Connection", "close");
  http.setTimeout(5000);
  http.setReuse(false);

  statusCode = http.POST(payload);
  response = statusCode > 0 ? http.getString() : "";
  http.end();

  return statusCode > 0;
}

size_t getQueueOffset() {
  preferences.begin("rfidpdks", true);
  size_t offset = preferences.getULong("queue_off", 0);
  preferences.end();
  return offset;
}

void setQueueOffset(size_t offset) {
  preferences.begin("rfidpdks", false);
  preferences.putULong("queue_off", offset);
  preferences.end();
}

size_t getPendingQueueBytes() {
  if (!queueStorageReady || !LittleFS.exists(OFFLINE_QUEUE_PATH)) return 0;
  File queueFile = LittleFS.open(OFFLINE_QUEUE_PATH, FILE_READ);
  if (!queueFile) return 0;
  size_t fileSize = queueFile.size();
  queueFile.close();
  size_t offset = getQueueOffset();
  if (offset > fileSize) {
    setQueueOffset(0);
    return fileSize;
  }
  return fileSize - offset;
}

void getQueueTelemetry(int& pendingCount, String& oldestQueuedAt) {
  pendingCount = 0;
  oldestQueuedAt = "";
  if (!queueStorageReady || !LittleFS.exists(OFFLINE_QUEUE_PATH)) return;

  File queueFile = LittleFS.open(OFFLINE_QUEUE_PATH, FILE_READ);
  if (!queueFile) return;
  size_t offset = getQueueOffset();
  if (offset >= queueFile.size() || !queueFile.seek(offset)) {
    queueFile.close();
    return;
  }

  while (queueFile.available()) {
    String line = queueFile.readStringUntil('\n');
    line.trim();
    if (line.length() == 0) continue;
    StaticJsonDocument<256> queuedScan;
    if (deserializeJson(queuedScan, line)) continue;
    pendingCount++;
    if (oldestQueuedAt.length() == 0) oldestQueuedAt = String(queuedScan["scannedAt"] | "");
  }
  queueFile.close();
}

bool getDeviceScanTime(String& timestamp) {
  time_t now = time(nullptr);
  if (now < 1704067200) return false;

  struct tm utcTime;
  gmtime_r(&now, &utcTime);
  char buffer[25];
  strftime(buffer, sizeof(buffer), "%Y-%m-%dT%H:%M:%SZ", &utcTime);
  timestamp = String(buffer);
  return true;
}

String createClientEventId() {
  String mac = getMacAddress();
  mac.replace(":", "");
  char randomPart[9];
  snprintf(randomPart, sizeof(randomPart), "%08lX", (unsigned long)esp_random());
  return mac + ":" + String((unsigned long)time(nullptr)) + ":" + String(randomPart);
}

bool enqueueCardScan(const String& cardId, String& eventId) {
  if (!queueStorageReady) return false;

  String scannedAt;
  if (!getDeviceScanTime(scannedAt)) {
    showLcd("Saat bilinmiyor", "Kayit alinmadi");
    errorSignal();
    return false;
  }

  StaticJsonDocument<256> queuedScan;
  eventId = createClientEventId();
  queuedScan["clientEventId"] = eventId;
  queuedScan["rfidCardId"] = cardId;
  queuedScan["scannedAt"] = scannedAt;

  String line;
  serializeJson(queuedScan, line);
  line += "\n";
  if (getPendingQueueBytes() + line.length() > OFFLINE_QUEUE_MAX_PENDING_BYTES) {
    showLcd("Kayit kuyrugu", "dolu");
    errorSignal();
    return false;
  }

  File queueFile = LittleFS.open(OFFLINE_QUEUE_PATH, FILE_APPEND);
  if (!queueFile) {
    showLcd("Kayit hafizasi", "acilamadi");
    errorSignal();
    return false;
  }
  size_t written = queueFile.print(line);
  queueFile.flush();
  queueFile.close();
  return written == line.length();
}

bool readNextQueuedScan(String& line, size_t& nextOffset) {
  if (!queueStorageReady || !LittleFS.exists(OFFLINE_QUEUE_PATH)) return false;
  File queueFile = LittleFS.open(OFFLINE_QUEUE_PATH, FILE_READ);
  if (!queueFile) return false;

  size_t offset = getQueueOffset();
  if (offset >= queueFile.size()) {
    queueFile.close();
    LittleFS.remove(OFFLINE_QUEUE_PATH);
    setQueueOffset(0);
    return false;
  }

  if (!queueFile.seek(offset)) {
    queueFile.close();
    return false;
  }
  line = queueFile.readStringUntil('\n');
  nextOffset = queueFile.position();
  queueFile.close();
  line.trim();
  return line.length() > 0;
}

void acknowledgeQueuedScan(size_t nextOffset) {
  File queueFile = LittleFS.open(OFFLINE_QUEUE_PATH, FILE_READ);
  size_t fileSize = queueFile ? queueFile.size() : 0;
  if (queueFile) queueFile.close();

  if (nextOffset >= fileSize) {
    LittleFS.remove(OFFLINE_QUEUE_PATH);
    setQueueOffset(0);
  } else {
    setQueueOffset(nextOffset);
  }
}

void showAcceptedScanResponse(const String& response, int statusCode, const String& cardId) {
  StaticJsonDocument<768> responseJson;
  DeserializationError error = deserializeJson(responseJson, response);
  if (error) {
    showLcd("Sunucu yaniti", "okunamadi");
    errorSignal();
    return;
  }

  if (statusCode == 404 && String(responseJson["code"] | "") == "UNKNOWN_CARD") {
    showLcd("T.siz kart =", cardId);
    unknownCardSignal();
    delay(5780);
    showIdleClock(true);
    return;
  }

  if (statusCode != 200 || !responseJson["success"]) {
    const char* apiError = responseJson["error"] | "Kart reddedildi";
    showLcd("Islem basarisiz", String(apiError));
    errorSignal();
    showIdleClock(true);
    return;
  }

  String firstName = String(responseJson["employee"]["firstName"] | "");
  String lastName = String(responseJson["employee"]["lastName"] | "");
  showLcd(firstName.length() > 0 ? firstName : "Personel", lastName);
  successSignal();
  delay(1805);
  showIdleClock(true);
}

bool flushQueuedScans(const String& currentEventId = "") {
  if (WiFi.status() != WL_CONNECTED || !queueStorageReady) return false;

  bool sentAny = false;
  for (int sentCount = 0; sentCount < MAX_QUEUE_SEND_PER_LOOP; sentCount++) {
    String queuedLine;
    size_t nextOffset = 0;
    if (!readNextQueuedScan(queuedLine, nextOffset)) break;

    StaticJsonDocument<384> queuedScan;
    if (deserializeJson(queuedScan, queuedLine)) {
      Serial.println("Bozuk kuyruk kaydi atlandi.");
      acknowledgeQueuedScan(nextOffset);
      continue;
    }

    String eventId = String(queuedScan["clientEventId"] | "");
    String cardId = String(queuedScan["rfidCardId"] | "");
    queuedScan["secretKey"] = deviceSecretKey;
    queuedScan["macAddress"] = getMacAddress();
    queuedScan["ipAddress"] = WiFi.localIP().toString();

    String payload;
    serializeJson(queuedScan, payload);
    String response;
    int statusCode = 0;
    if (!postJson("/api/device/rfid/scan", payload, response, statusCode)) {
      lastSendError = "RFID gonderimi basarisiz: " + String(statusCode);
      break;
    }

    bool accepted = statusCode == 200;
    bool permanentlyRejected = statusCode == 400 || statusCode == 401 ||
                               statusCode == 403 || statusCode == 404;
    if (!accepted && !permanentlyRejected) {
      lastSendError = "RFID sunucu hatasi: HTTP " + String(statusCode);
      break;
    }

    acknowledgeQueuedScan(nextOffset);
    if (accepted) lastSendError = "";
    sentAny = true;
    Serial.println("Kuyruk kaydi gonderildi: " + eventId + " HTTP " + String(statusCode));
    if (eventId == currentEventId) showAcceptedScanResponse(response, statusCode, cardId);
  }
  return sentAny;
}
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
void loop() {
  if (isConfigPortalActive) {
    dnsServer.processNextRequest();
    configServer.handleClient();
    if (!otaInProgress) readRfidIfAvailable();
    retrySavedWifiFromConfigPortal();
    if (!isConfigPortalActive) {
      delay(30);
      return;
    }
    delay(10);
    return;
  }

  connectWifiIfNeeded();

  if (WiFi.status() == WL_CONNECTED) {
    unsigned long now = millis();
    if (!bootOtaResultReported) {
      reportBootFirmwareResult();
      bootOtaResultReported = true;
    }
    if (now - lastHeartbeatAt >= HEARTBEAT_INTERVAL_MS) {
      lastHeartbeatAt = now;
      sendHeartbeat();
    }

    if (!otaInProgress && (long)(now - nextFirmwareCheckAt) >= 0) {
      bool checkSucceeded = checkFirmwareUpdate();
      nextFirmwareCheckAt = millis() + (checkSucceeded ? OTA_CHECK_INTERVAL_MS : OTA_RETRY_INTERVAL_MS);
    }

    if (!otaInProgress && now - lastQueueFlushAt >= QUEUE_FLUSH_INTERVAL_MS) {
      lastQueueFlushAt = now;
      flushQueuedScans();
    }

    if (!otaInProgress) {
      readRfidIfAvailable();
      showIdleClock();
    }
  } else if (!otaInProgress) {
    readRfidIfAvailable();
  }

  delay(30);
}

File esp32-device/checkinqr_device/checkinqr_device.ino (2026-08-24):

#include <WiFi.h>
#include <WebServer.h>
#include <DNSServer.h>
#include <Preferences.h>
#include <HTTPClient.h>
#include <WiFiClientSecure.h>
#include <ArduinoJson.h>
#include <Adafruit_GFX.h>
#include <Adafruit_SSD1306.h>
#include <qrcode.h>

#define SCREEN_WIDTH 128
#define SCREEN_HEIGHT 64
#define OLED_RESET -1
#define OLED_ADDRESS 0x3C
#define WIFI_STATUS_LED_PIN 5

const char* DEFAULT_WIFI_SSID = "";
const char* DEFAULT_WIFI_PASSWORD = "";

const char* API_BASE_URL = "https://flodeka.com";
const char* DEVICE_SECRET_KEY = "489cc5a0-db71-4b07-a0d5-2080a1cde546";

const unsigned long WIFI_RETRY_MS = 5000;
const unsigned long WIFI_CONNECT_TIMEOUT_MS = 15000;
const unsigned long SYNC_INTERVAL_MS = 1000;
const byte DNS_PORT = 53;

Adafruit_SSD1306 display(SCREEN_WIDTH, SCREEN_HEIGHT, &Wire, OLED_RESET);
Preferences preferences;
WebServer configServer(80);
DNSServer dnsServer;

String currentQrToken = "";
String currentDeviceName = "";
String savedWifiSsid = "";
String savedWifiPassword = "";
String setupApSsid = "";
unsigned long lastWifiAttemptAt = 0;
unsigned long lastSyncAt = 0;
bool hasRenderedQr = false;
bool isConfigPortalActive = false;

void updateWifiStatusLed() {
  digitalWrite(WIFI_STATUS_LED_PIN, WiFi.status() == WL_CONNECTED ? HIGH : LOW);
}

bool isHttpsUrl(const String& url) {
  return url.startsWith("https://");
}

String htmlEscape(const String& value) {
  String escaped = value;
  escaped.replace("&", "&amp;");
  escaped.replace("<", "&lt;");
  escaped.replace(">", "&gt;");
  escaped.replace("\"", "&quot;");
  return escaped;
}

String getApSsid() {
  uint64_t chipId = ESP.getEfuseMac();
  char suffix[7];
  snprintf(suffix, sizeof(suffix), "%06X", (uint32_t)(chipId & 0xFFFFFF));
  return "RFIDPersonel-" + String(suffix);
}

void loadWifiCredentials() {
  preferences.begin("rfidpersonel", true);
  savedWifiSsid = preferences.getString("wifi_ssid", DEFAULT_WIFI_SSID);
  savedWifiPassword = preferences.getString("wifi_pass", DEFAULT_WIFI_PASSWORD);
  preferences.end();
}

void saveWifiCredentials(const String& ssid, const String& password) {
  preferences.begin("rfidpersonel", false);
  preferences.putString("wifi_ssid", ssid);
  preferences.putString("wifi_pass", password);
  preferences.end();
  savedWifiSsid = ssid;
  savedWifiPassword = password;
}

void drawCenteredText(const String& text, int y, int textSize) {
  display.setTextSize(textSize);
  display.setTextColor(SSD1306_WHITE);

  int16_t x1;
  int16_t y1;
  uint16_t width;
  uint16_t height;
  display.getTextBounds(text, 0, y, &x1, &y1, &width, &height);
  int x = (SCREEN_WIDTH - width) / 2;
  display.setCursor(x, y);
  display.print(text);
}

void drawStatusScreen(const String& title, const String& line1 = "", const String& line2 = "") {
  display.clearDisplay();
  drawCenteredText(title, 8, 1);

  if (line1.length() > 0) {
    drawCenteredText(line1, 28, 1);
  }

  if (line2.length() > 0) {
    drawCenteredText(line2, 44, 1);
  }

  display.display();
}

void drawConfigPortalScreen() {
  drawStatusScreen("Wi-Fi Kurulum", setupApSsid, "IP: 192.168.4.1");
}

void drawFooterStatus(const String& text) {
  display.fillRect(0, 52, SCREEN_WIDTH, 12, SSD1306_BLACK);
  display.setTextSize(1);
  display.setTextColor(SSD1306_WHITE);
  display.setCursor(0, 54);
  display.print(text);
  display.display();
}

void drawQrCode(const String& token) {
  display.clearDisplay();
  display.fillScreen(SSD1306_WHITE);

  QRCode qrcode;
  const uint8_t qrVersion = token.length() <= 17 ? 1 : (token.length() <= 32 ? 2 : 4);
  uint8_t qrcodeData[qrcode_getBufferSize(4)];
  int8_t qrResult = qrcode_initText(&qrcode, qrcodeData, qrVersion, ECC_LOW, token.c_str());

  if (qrResult < 0) {
    display.clearDisplay();
    drawStatusScreen("QR hatasi", "Token cok uzun");
    hasRenderedQr = false;
    return;
  }

  const int qrSize = qrcode.size;
  const bool showDeviceName = qrSize * 2 <= 50;
  const int usableHeight = showDeviceName ? 52 : SCREEN_HEIGHT;
  const int scale = (qrSize * 2 <= usableHeight - 2) ? 2 : 1;
  const int qrPixelSize = qrSize * scale;
  const int xOffset = (SCREEN_WIDTH - qrPixelSize) / 2;
  const int yOffset = (usableHeight - qrPixelSize) / 2;

  for (int y = 0; y < qrSize; y++) {
    for (int x = 0; x < qrSize; x++) {
      if (qrcode_getModule(&qrcode, x, y)) {
        display.fillRect(xOffset + (x * scale), yOffset + (y * scale), scale, scale, SSD1306_BLACK);
      }
    }
  }

  if (showDeviceName) {
    display.fillRect(0, 52, SCREEN_WIDTH, 12, SSD1306_BLACK);
    display.setTextSize(1);
    display.setTextColor(SSD1306_WHITE);
    display.setCursor(0, 54);
    display.print(currentDeviceName.length() > 0 ? currentDeviceName : "RFID Device");
  }

  display.display();
  hasRenderedQr = true;
}

bool tryConnectWifi(const String& ssid, const String& password) {
  if (ssid.length() == 0) {
    return false;
  }

  Serial.print("Wi-Fi deneniyor: ");
  Serial.println(ssid);
  drawStatusScreen("Wi-Fi baglaniliyor", ssid);

  WiFi.mode(WIFI_STA);
  WiFi.setSleep(false);
  WiFi.setAutoReconnect(true);
  WiFi.begin(ssid.c_str(), password.c_str());

  unsigned long connectStart = millis();
  while (WiFi.status() != WL_CONNECTED && millis() - connectStart < WIFI_CONNECT_TIMEOUT_MS) {
    delay(300);
  }

  if (WiFi.status() == WL_CONNECTED) {
    Serial.print("Wi-Fi baglandi. IP: ");
    Serial.println(WiFi.localIP());
    updateWifiStatusLed();
    drawStatusScreen("Wi-Fi baglandi", WiFi.localIP().toString());
    delay(900);
    return true;
  }

  Serial.println("Wi-Fi baglantisi kurulamadi.");
  WiFi.disconnect(true);
  updateWifiStatusLed();
  delay(300);
  return false;
}

String buildWifiOptionsHtml() {
  int networkCount = WiFi.scanNetworks();
  String options = "";

  if (networkCount <= 0) {
    return "<option value=\"\">Ag bulunamadi</option>";
  }

  for (int i = 0; i < networkCount; i++) {
    String ssid = WiFi.SSID(i);
    if (ssid.length() == 0) {
      continue;
    }
    options += "<option value=\"" + htmlEscape(ssid) + "\">";
    options += htmlEscape(ssid) + " (" + String(WiFi.RSSI(i)) + " dBm)";
    options += "</option>";
  }

  WiFi.scanDelete();
  return options;
}
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

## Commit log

2026-08-24 Add leave management and richer personnel devices
2026-08-24 Add manager definitions and split device reports flow
2026-08-25 Add date filter to critical personnel overview
2026-08-26 Fix assignment company filter typing
2026-08-26 Add user scoped company and device access
2026-08-26 Refine admin user and device access flows
2026-08-26 Add role definitions and user device assignment
2026-08-26 Refine user device ownership flow
2026-08-27 Add ESP32 RFID device workflow
2026-08-27 Add company and branch filters to movements
2026-08-28 Update ESP32 firmware for parallel LCD
2026-09-14 Add completed RFID device hardware files
    [govde.stl, govde_v2.stl, govde_v3.stl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]
2026-09-14 Improve RFID feedback and attendance reporting
    [gövde.stl, kapak.stl]
2026-09-22 Show live device connectivity and last activity for admin users
2026-09-22 Revise RFID analysis and operation filters
2026-09-23 Add V4 enclosure PCB carrier prototype design and review packet
    [bom.csv, connections.csv, rfid_carrier_v01.kicad_pcb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]
2026-09-24 Improve definitions and personnel filtering
2026-09-25 Retry saved Wi-Fi from device setup mode
2026-09-25 Add routed PCB prototype and hardware routing tools
    [bom.csv, connections.csv, rfid_carrier_v01.dsn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]
2026-09-25 Add managed ESP32 OTA firmware updates
2026-09-25 Correct OTA service domains
    [rfid_personel_device_ota.ino, rfid_personel_device_ota_test.ino, rfid_personel_device_ota_test_update.ino]
2026-09-25 Add live single-device OTA test firmware
2026-09-25 Ignore Arduino build caches
2026-09-27 Add attendance review device health and payroll locking
2026-10-02 feat: list RFID device health on server dashboard
2026-10-07 feat: improve personnel photo and movement filters
2026-10-07 Add filtered operation summary PDFs
2026-10-13 feat: self sign-up with 14-day trial and module licensing
    - Public /register page and API: new owners sign up themselves and get a
    14-day trial during which every module is open.
    - New "Modüller ve Lisanslar" page (/dashboard/store) with module info,
    trial status and Shopier purchase links; owners without an open module
    or company land there.
    - Trial and per-module license expiry are evaluated on each request, so
    access closes automatically when the trial ends without a purchase.
    - Admin user screen: license state, trial end date and per-module license
    with optional expiry; user list shows status with a filter.
    - Module definitions: Shopier link and price label per module.
    - Fix: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
2026-10-14 feat: Muhasebe personnel salary can be gross or net
    - Personel Tanımları stores a salary type (Brüt / Net) with the amount.
    - "Personel tanımlarından aktar" is available on both sheets: gross-salaried
    personnel go to Brütten Nete, net-salaried personnel to Netten Brüte. The
    button stays visible and explains when no matching personnel exists.
    - Personnel CSV template gets a Maaş Tipi column; without it the amount
    header (Brüt/Net Maaş) decides.
2026-10-15 feat: hide Üretim Planlama from everyone but super admin; remove invitation links
    Production planning is not released yet: company authorization, the module
    store and company screens filter it out (stored role/license rows are kept).
    Invitation links were unused since admins create users directly; the create
    and activate actions and the /activate page are removed.
2026-10-16 feat: lock Muhasebe CSV/PDF transfer during the free trial
    Trial-only companies see CSV import, CSV export and PDF export as passive
    buttons with an explanation and a link to the module store; a paid
    ACCOUNTING license enables them. importAccountingPersonnelAction rejects
    trial callers on the server, and printing the budget report shows only
    the license notice while locked.
2026-10-16 feat(site): budget report slide, Muhasebe page, purchase buttons and payroll article
    - Hero slider gets a second slide: a coded Bütçe Raporu preview with
    consistent sample data, tab navigation, pause control and reduced-motion
    support.
    - New /moduller/muhasebe page (features, premium rates, FAQ + JSON-LD).
    - Every module card, module page and blog post shows "Satın al" (Shopier
    link the super admin enters under Ayarlar > Modüller) and "Ücretsiz dene";
    narrow screens get a fixed buy bar. Pages revalidate every 5 minutes and
    on catalog save.
    - SEO article on gross-to-net salary and employer cost; figures checked
    against salary-calculation.ts 2026 parameters.
    - Quieter visual l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
2026-10-16 feat(site): slider right under the header, tinted section bands
    - Home page opens with the module slider; the intro copy and buttons above
    it are gone (heading kept for screen readers and search engines).
    - Sections alternate white and a cool tint, page heads and the CTA band
    are tinted and the footer is dark, so section changes are visible.
2026-10-19 feat(site): full-width hero slider with the budget report visual
    - Slider visuals span the full viewport width right under the header;
    tabs and the active slide's caption with purchase/trial buttons sit
    below in the page container.
    - Pause and previous/next buttons removed; choosing a tab stops the
    automatic rotation.
    - Second slide uses the Muhasebe budget report visual.
2026-10-20 feat(auth): email verification, password reset and Flodeska branding
    - Self-registered users must verify their e-mail before signing in; pending
    Shopier licenses are claimed only after verification.
    - Forgot/reset password flow with single-use hashed tokens (1 hour).
    - Shared SMTP mailer; login/register/dashboard show Flodeska instead of RFID Personel Takip.
2026-10-21 feat(device): firmware 1.2.1 with RC522 recovery, watchdog and nightly restart
2026-10-21 feat(smart-home): USB-serial mesh root bridge and resilient sync
    - Pi agent talks to the mesh root ESP32 over USB serial (no MQTT broker)
    - Simulator mode to test panel <-> Pi before hardware arrives
    - Node lastSeenAt comes from the agent, so unplugged nodes go offline
    - Invalid nodes/acks are skipped instead of rejecting the whole sync
    - Document serial protocol and register the akilli-ev agent
2026-10-22 feat(smart-home): wake home computers over LAN from the panel
    The Pi agent exposes configured computers as wake-only nodes, sends a
    magic packet on SET_POWER and reports power from an RDP/SMB/ping check.
2026-10-23 feat(platform): create company at sign-up and guide first-run setup
    - Self sign-up now asks for the company name and creates the company,
    ready roles and owner membership in the same transaction.
    - Operation summary shows a setup checklist to company owners until the
    company reads cards from its own device.
    - Trial companies can try a demo card read that uses the same movement
    inference as a real bidirectional reader.
    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
2026-10-23 feat(hardware): finish PCB V0.2 with GND pour, silk marks and Gerbers
    Add GND pours on both layers, assembly marks on F.SilkS (pin-1 dots,
    electrolytic +, D1 cathode bar, Q1 C/B/E), trim the dangling GPIO22
    tail and export Gerber/Excellon files, DRC report, render and 1:1 SVG.
2026-10-30 fix(reports): address review findings on reports rebuild
    - Index night-shift windows per employee instead of scanning all windows
    - Reject impossible dates like 2026-02-30 in report filters
    - Personnel row attendance rate excludes leave days, like the KPIs
    - Late report counts only employees with planned or worked days
    - Measured break column only for break-tracking companies in the xlsx export
    - Fill missing fields on any snapshot version; update MODULE notes
2026-11-06 chore(hardware): add rfid carrier v02 gerber export
